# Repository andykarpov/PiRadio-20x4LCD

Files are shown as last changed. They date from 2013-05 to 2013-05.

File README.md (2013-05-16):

PiRadio-20x4LCD
=======

Python based internet radio project for RaspberryPi to play internet radio streams and control it using custom atmega328p-based board with 
connected 20x4 character display, rotary encoder, potentiometer, 2xMSGEQ7 board and PT2322 audio processor board.

All hardware-specific EAGLE projects are located under 'schematic' subfolder. 
All required non-standard libraries are available upon request. Some of them are self-made from scratch, some of them googled in the internet.

**Prerequesties:**

1. You should have a working raspberry pi with latest raspbian (at least 2012-12-18)
2. Also we assumes that your network connection (wired or wireless) is also running well
3. Your arduino-based board is connected via internal on-board serial port  
   (assuming arduino/PyRadioInterface sketch is already uploaded there, all external hardware is connected to the arduino - 
   such as rotary encoder, potentiometer, PT2322 board, MSGEQ7 board)
4. You are logged in as user 'pi' with it's default home at /home/pi/ 

**Installation:**

1. sudo apt-get update && sudo apt-get upgrade
2. sudo apt-get install mpd mpc python-serial python-mpd2 git
3. cd && git clone https://github.com/andykarpov/PiRadio-20x4LCD.git PiRadio
4. cd /home/pi/PiRadio
5. sudo ln -s /home/pi/PiRadio/etc/init.d/pi-radio /etc/init.d/pi-radio
6. chmod -R a+rwx data/ 
7. cd /home/pi/PiRadio/init.d/
8. sudo chmod a+x pi-radio
9. sudo nano /etc/mpd - change "localhost" to "any"
10. sudo alsamixer - set a desired output level
11. sudo alsactl store
12. sudo /etc/init.d/pi-radio start
13. sudo update-rc.d pi-radio defaults
14. sudo reboot

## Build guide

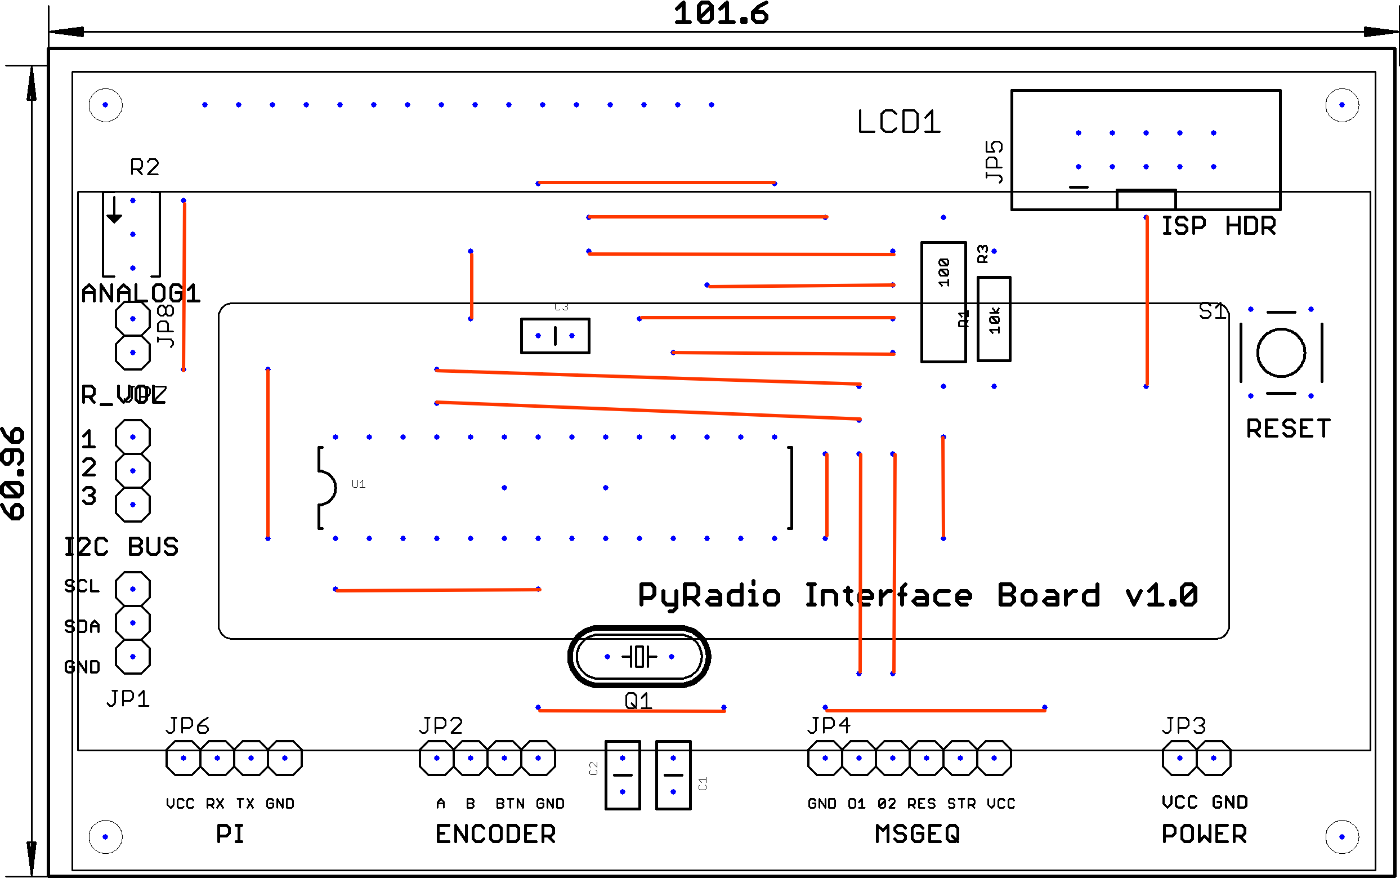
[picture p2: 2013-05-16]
schematic/build/png/interface_v_1_0_pcb_cmp_jumpered.png

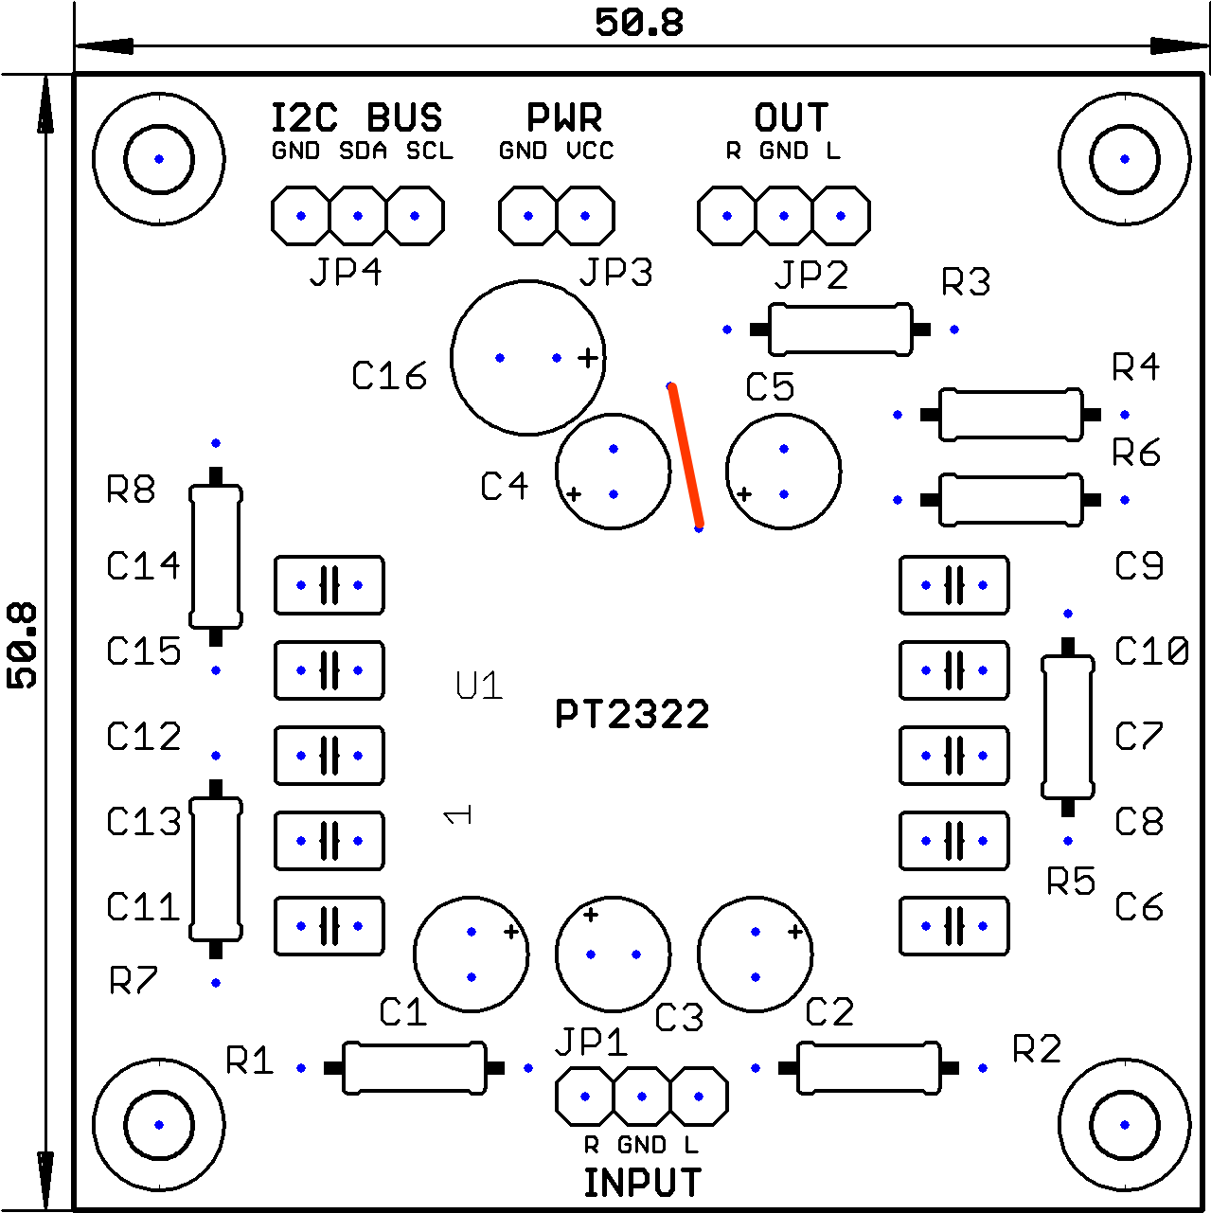
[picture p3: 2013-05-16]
schematic/build/png/pt2322_v_1_0_pcb_cmp_jumpered.png

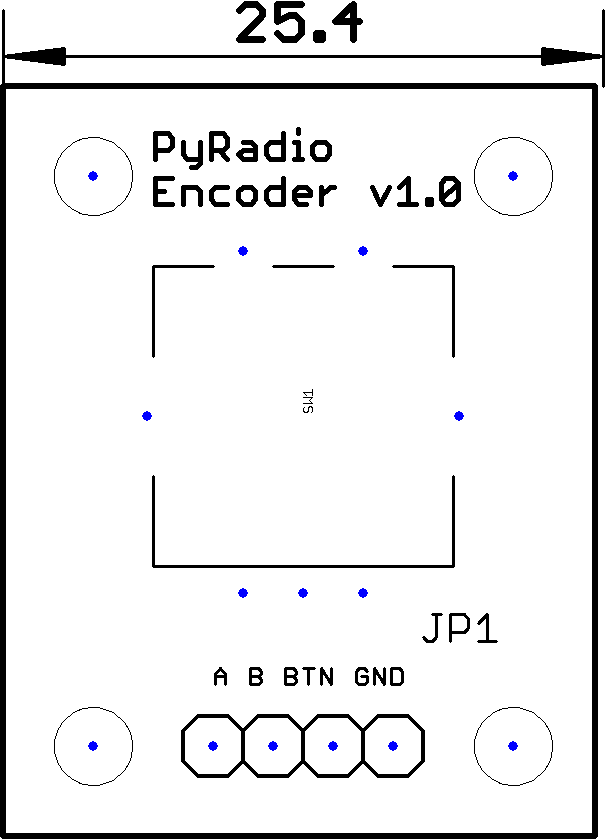
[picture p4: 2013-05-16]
schematic/build/png/encoder_v_1_0_pcb_cmp.png

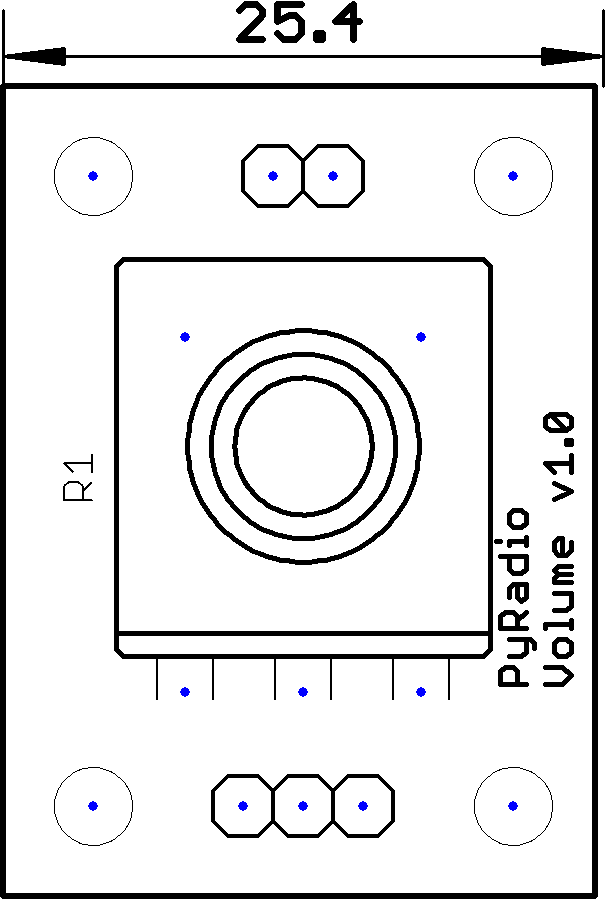
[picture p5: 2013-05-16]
schematic/build/png/volume_v_1_0_pcb_cmp.png

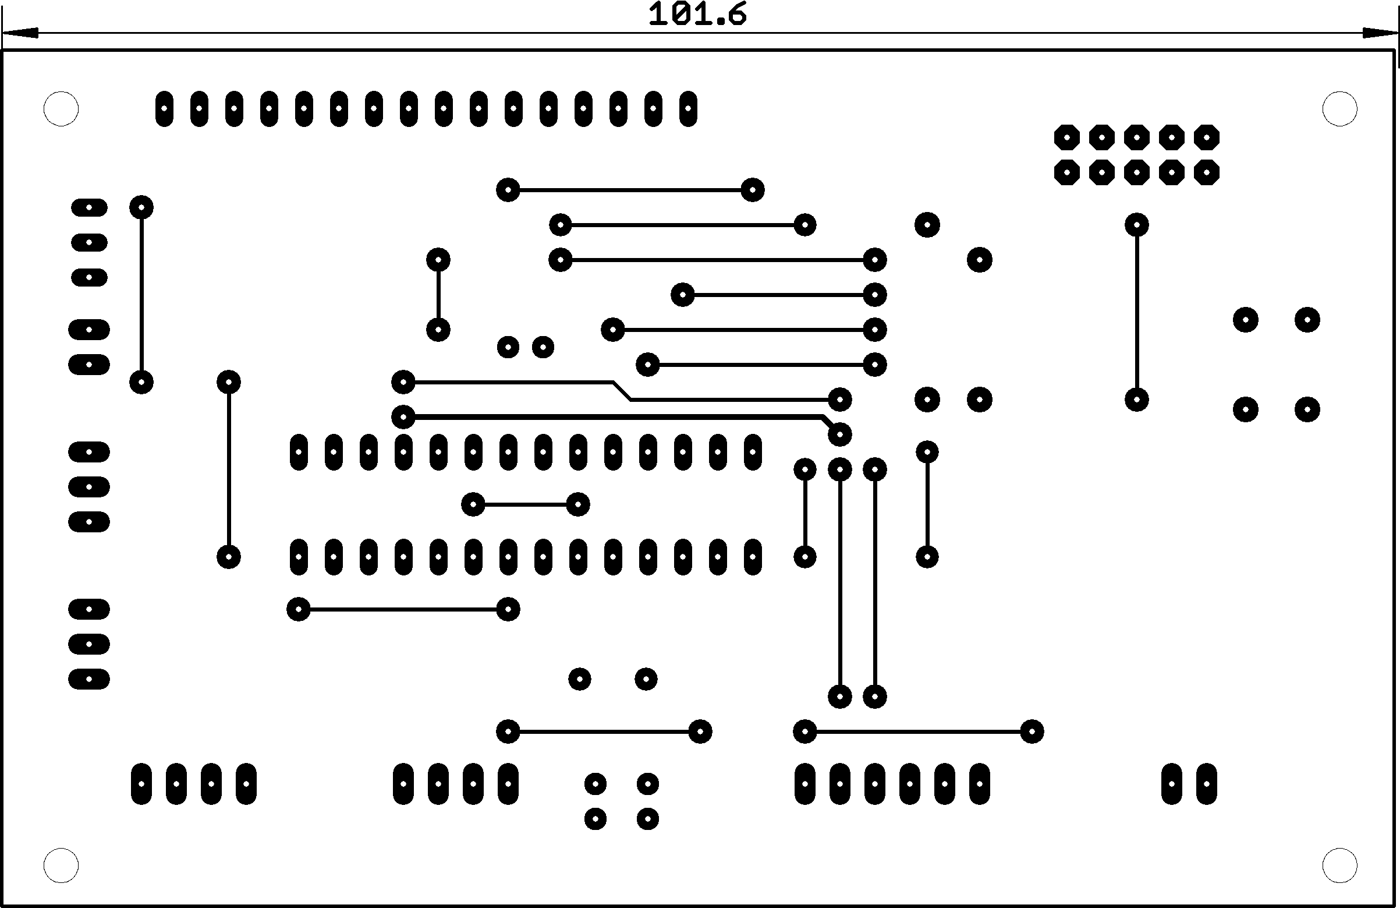
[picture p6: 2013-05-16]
schematic/build/png/interface_v_1_0_pcb_top.png

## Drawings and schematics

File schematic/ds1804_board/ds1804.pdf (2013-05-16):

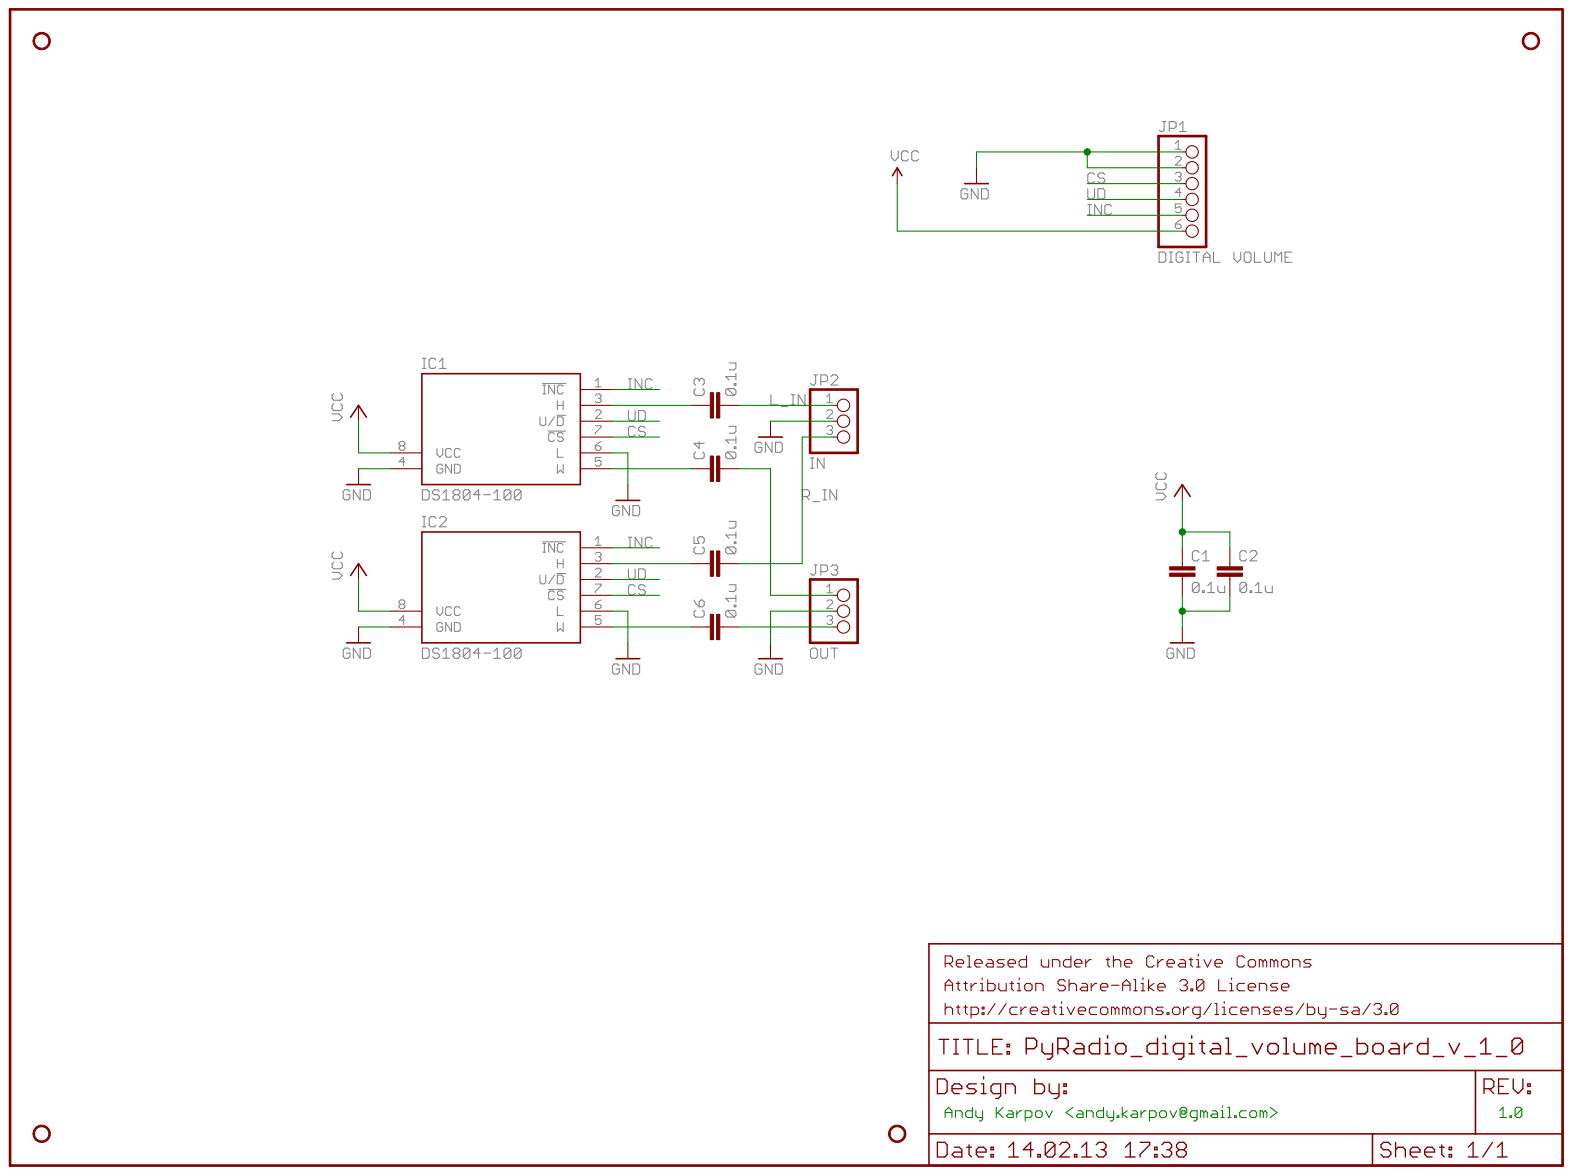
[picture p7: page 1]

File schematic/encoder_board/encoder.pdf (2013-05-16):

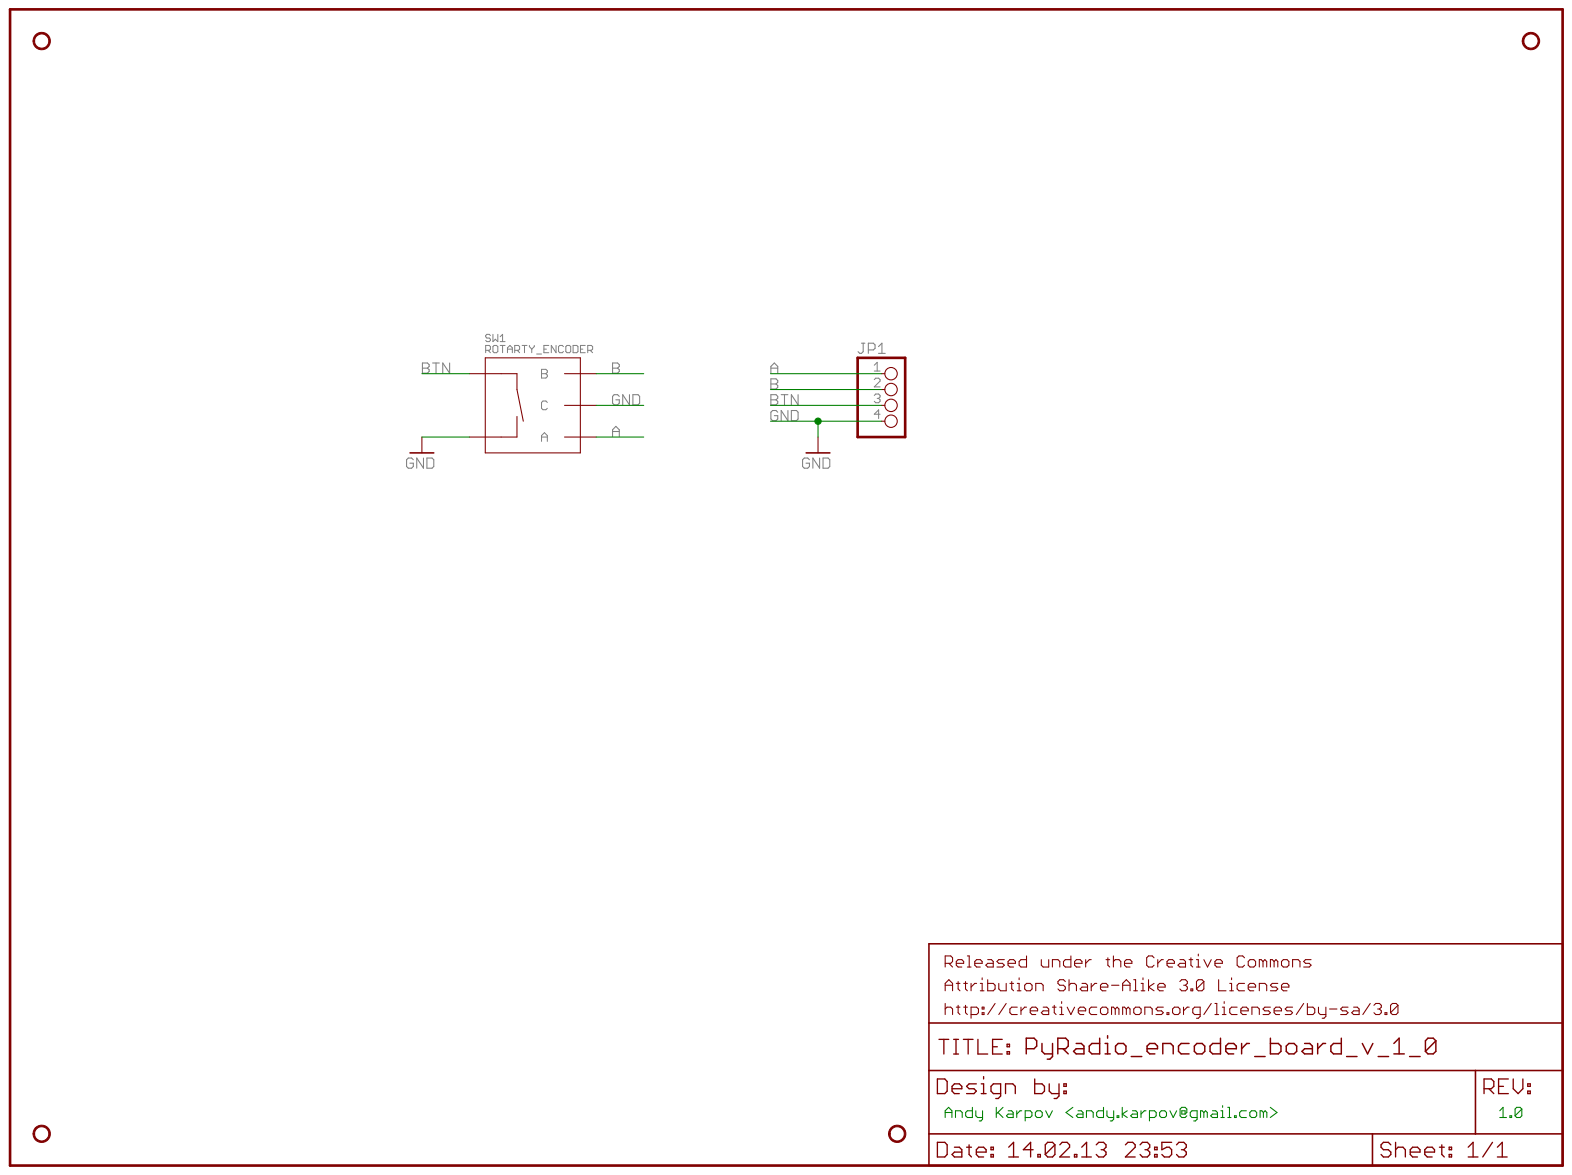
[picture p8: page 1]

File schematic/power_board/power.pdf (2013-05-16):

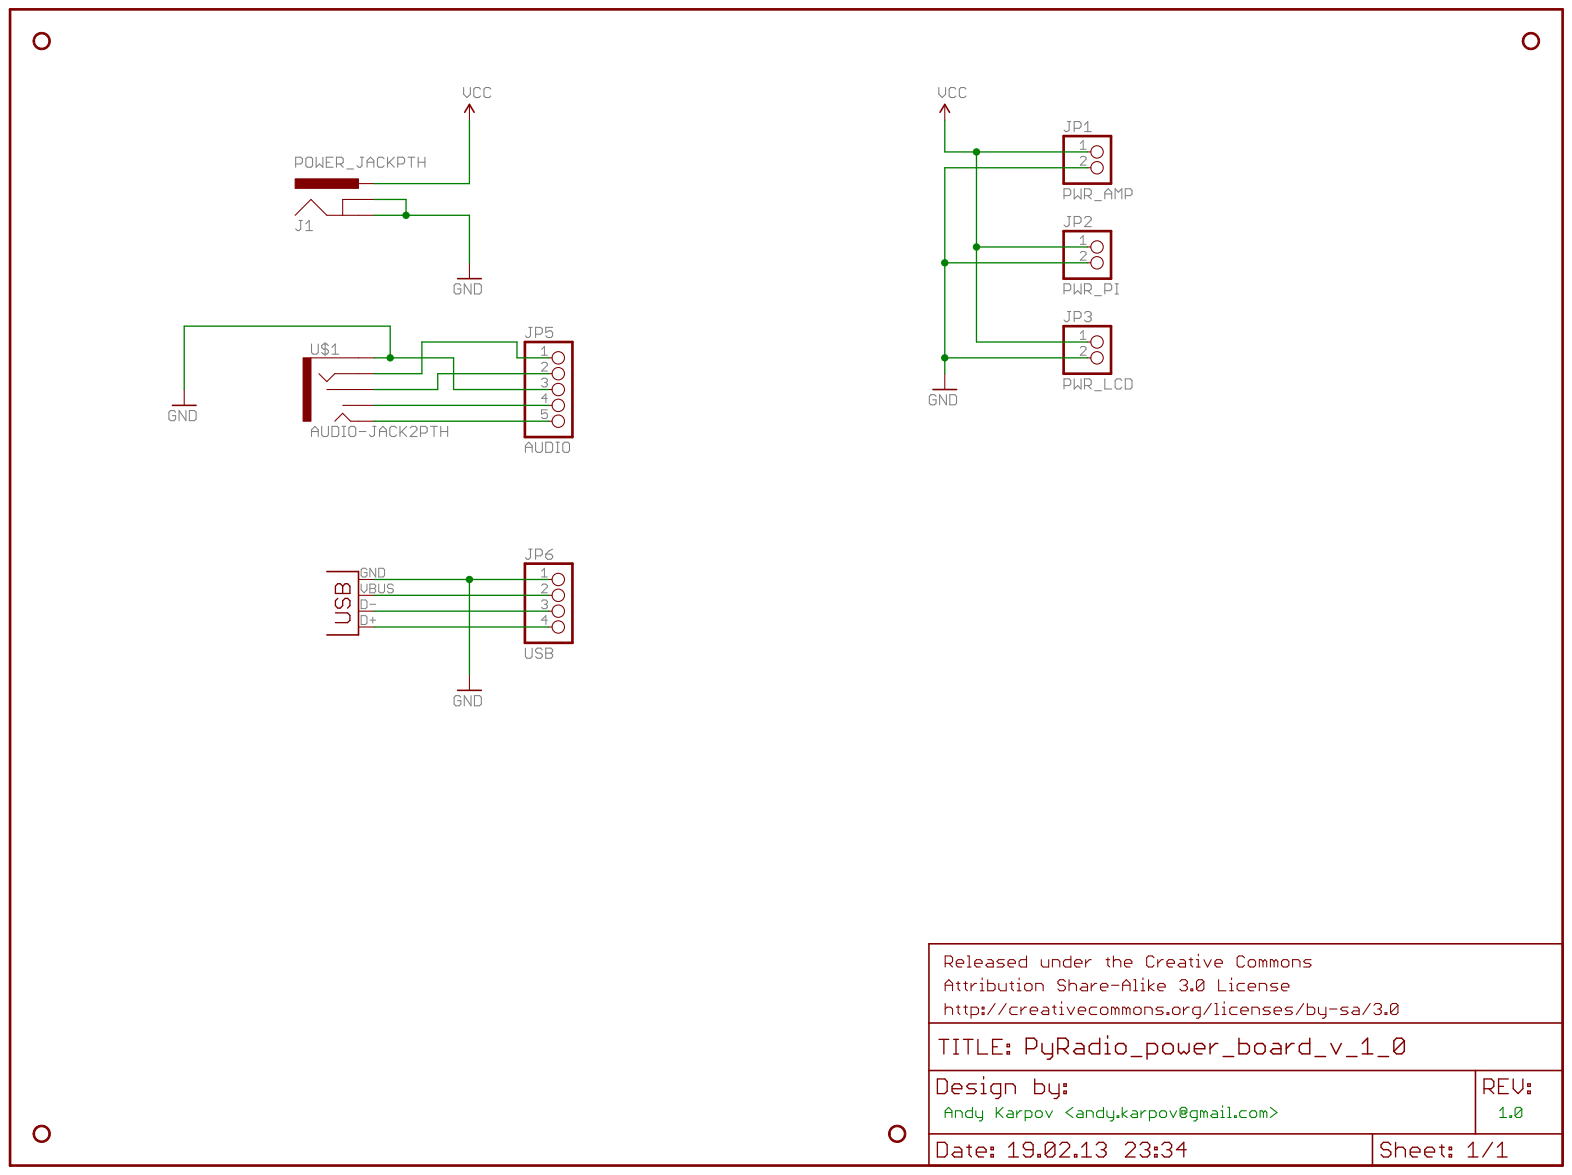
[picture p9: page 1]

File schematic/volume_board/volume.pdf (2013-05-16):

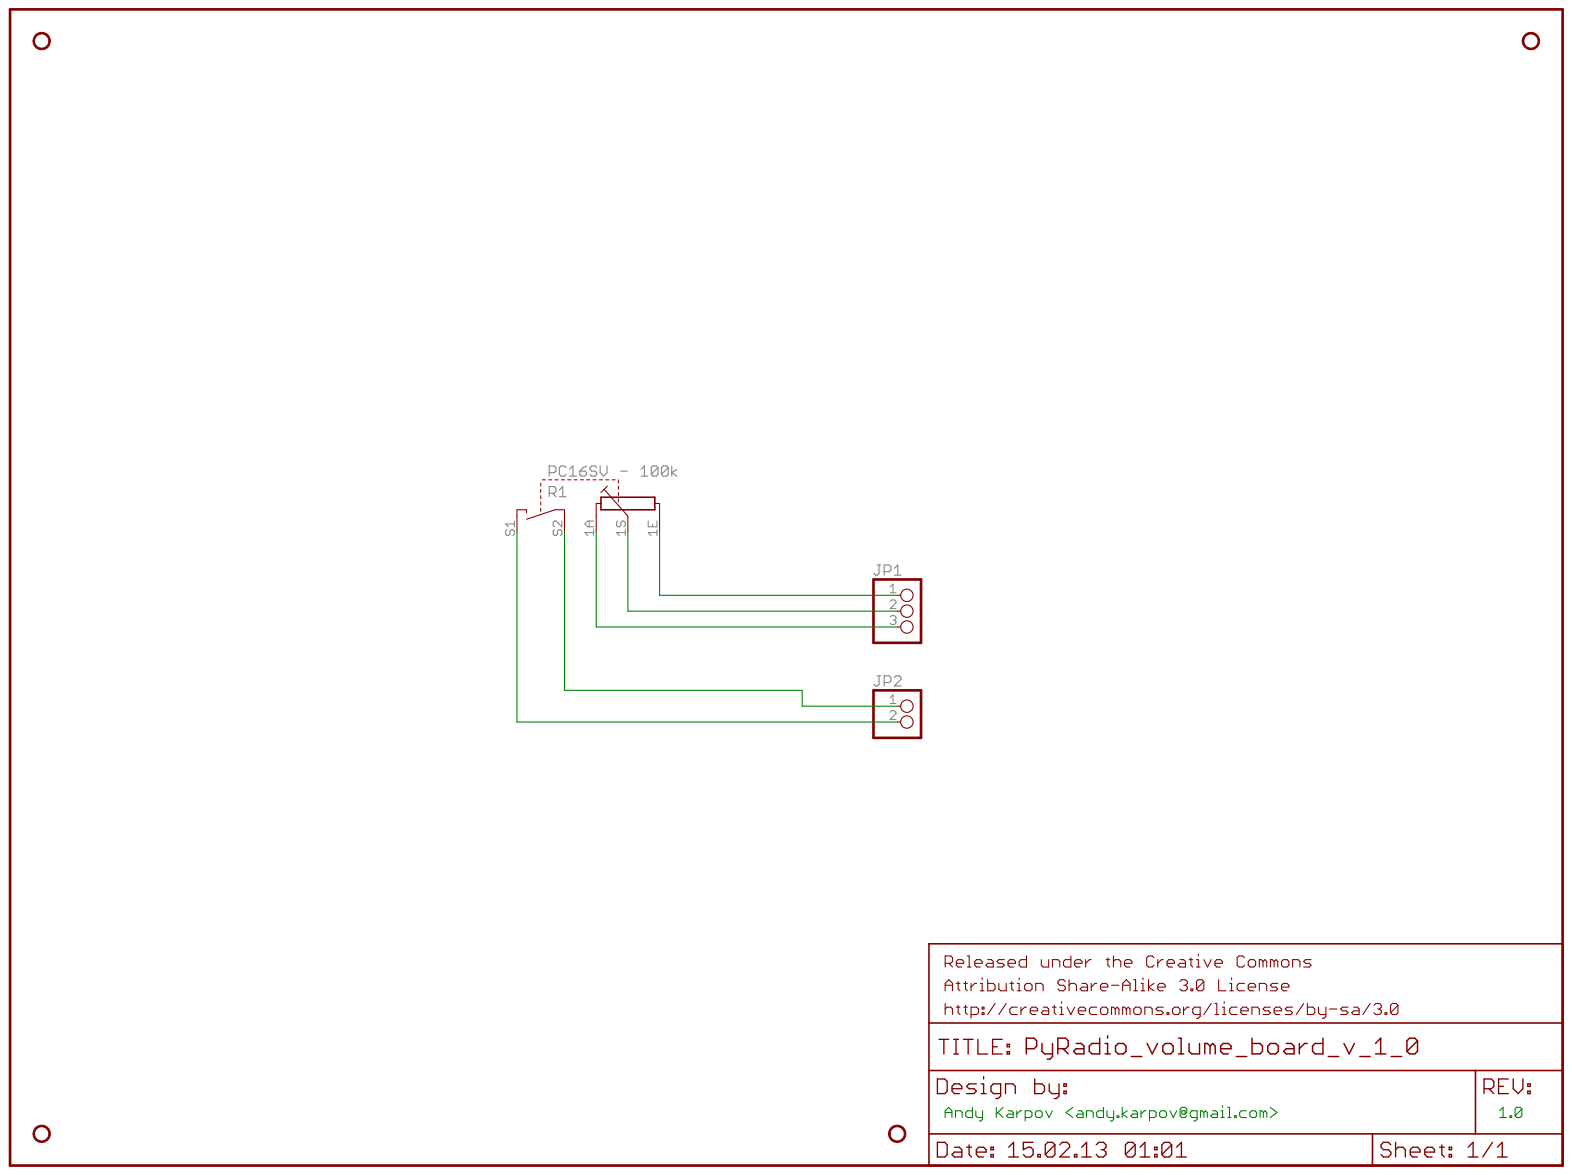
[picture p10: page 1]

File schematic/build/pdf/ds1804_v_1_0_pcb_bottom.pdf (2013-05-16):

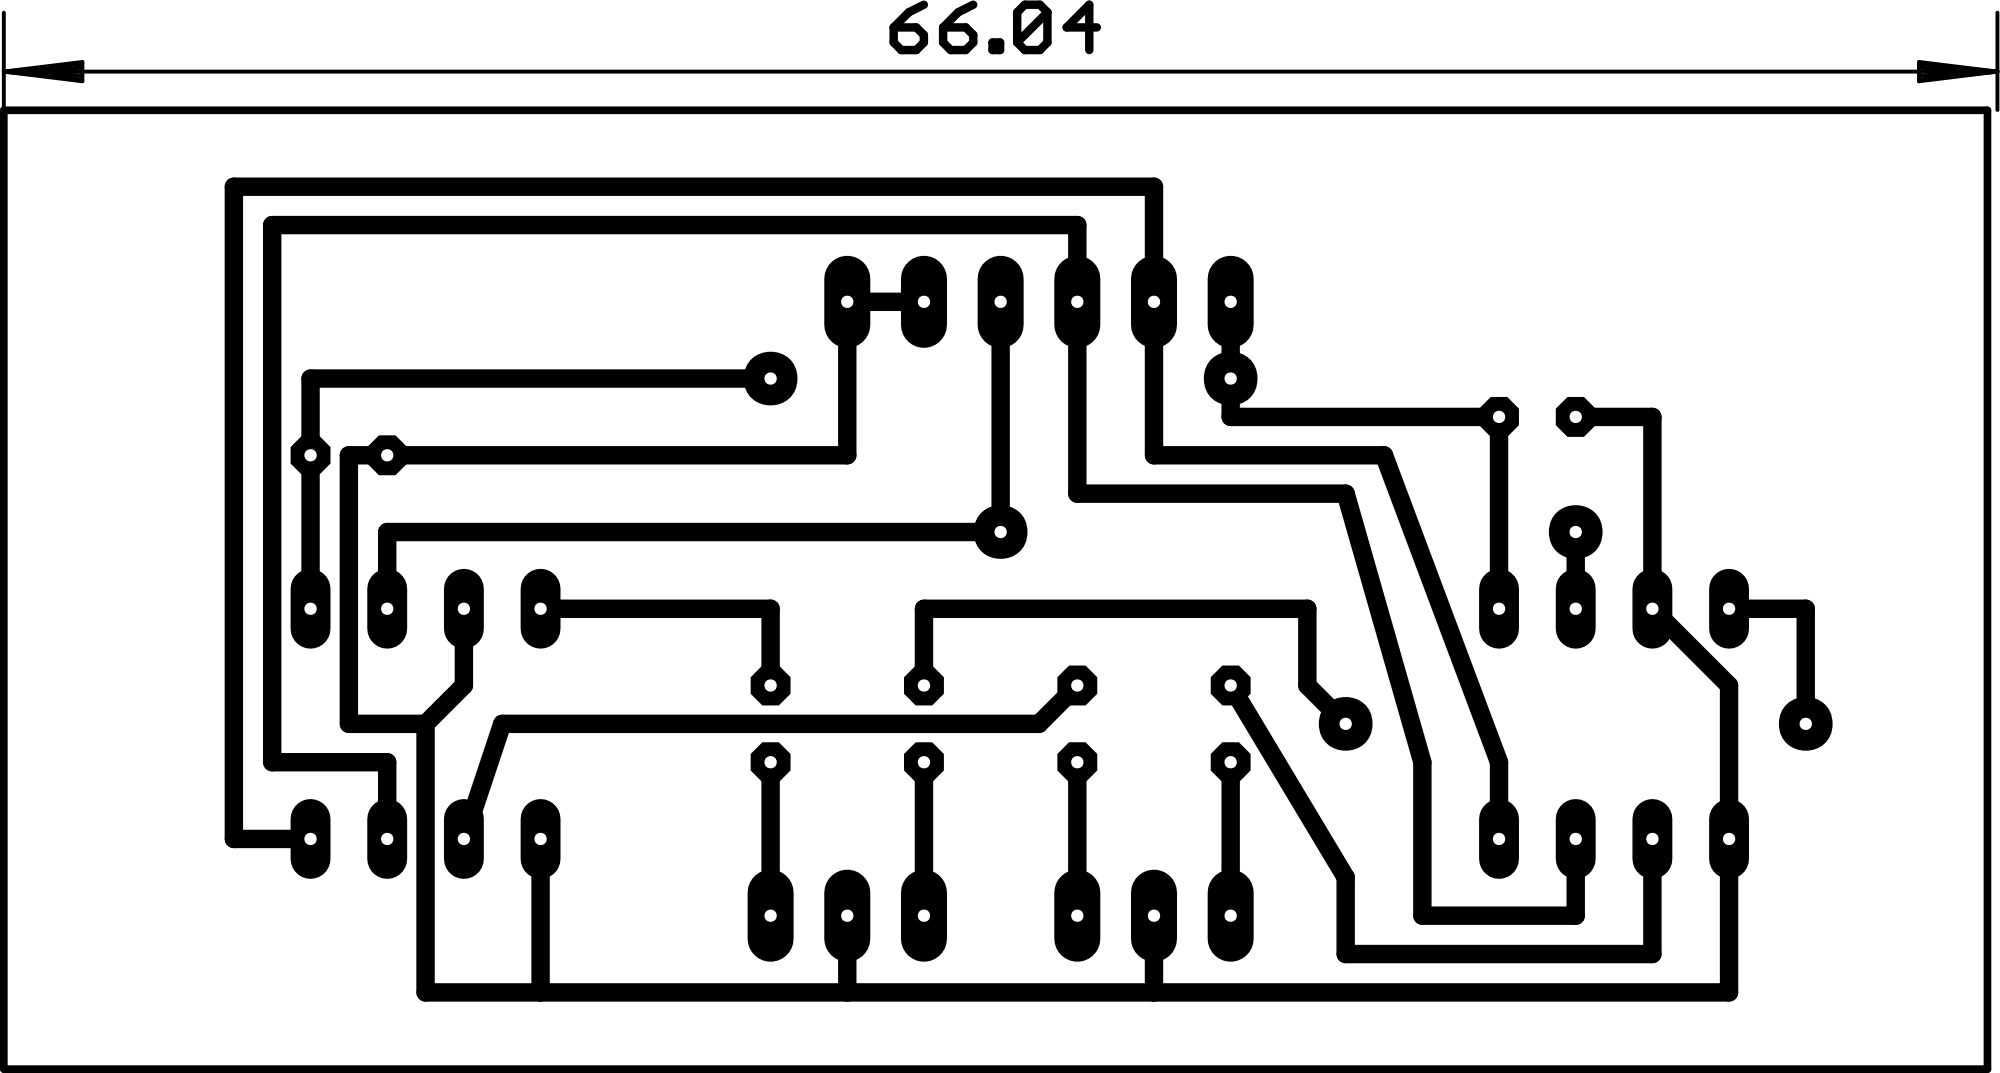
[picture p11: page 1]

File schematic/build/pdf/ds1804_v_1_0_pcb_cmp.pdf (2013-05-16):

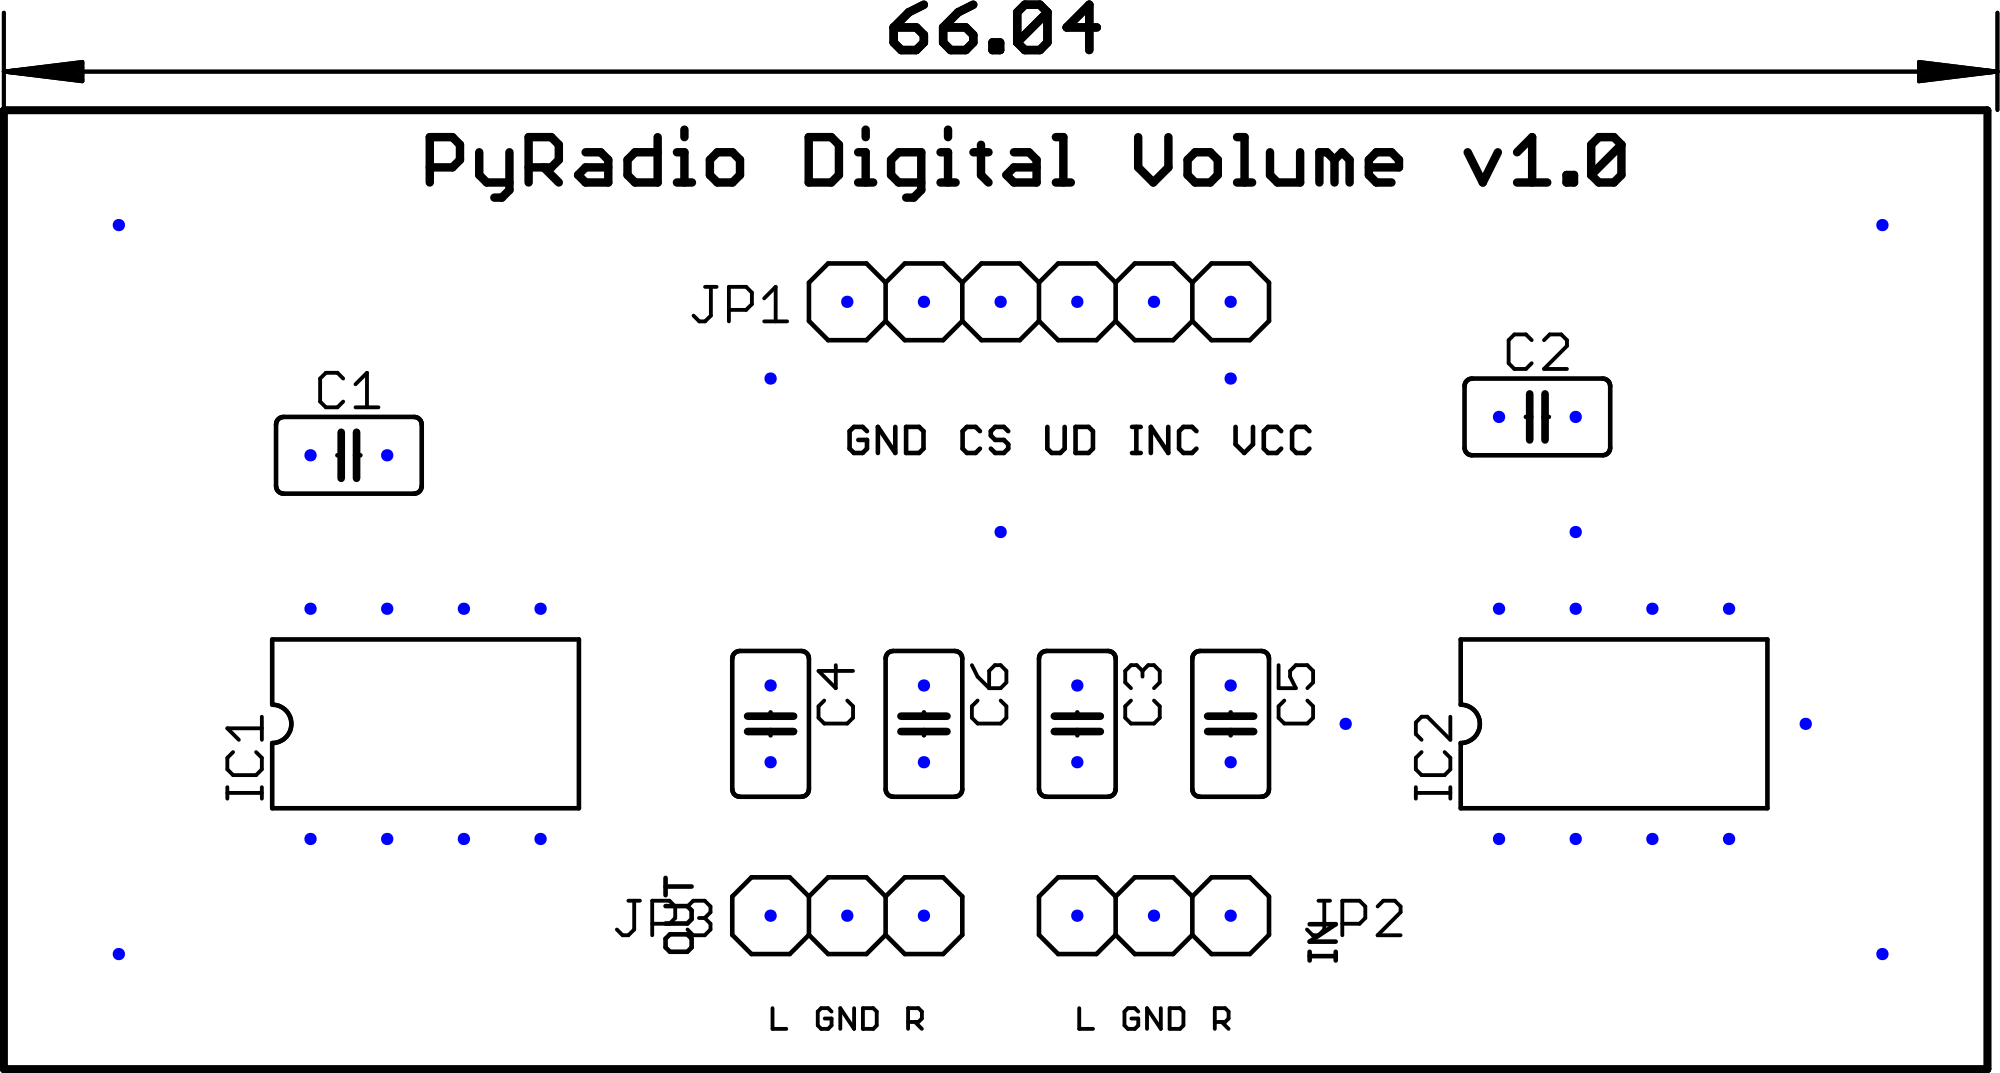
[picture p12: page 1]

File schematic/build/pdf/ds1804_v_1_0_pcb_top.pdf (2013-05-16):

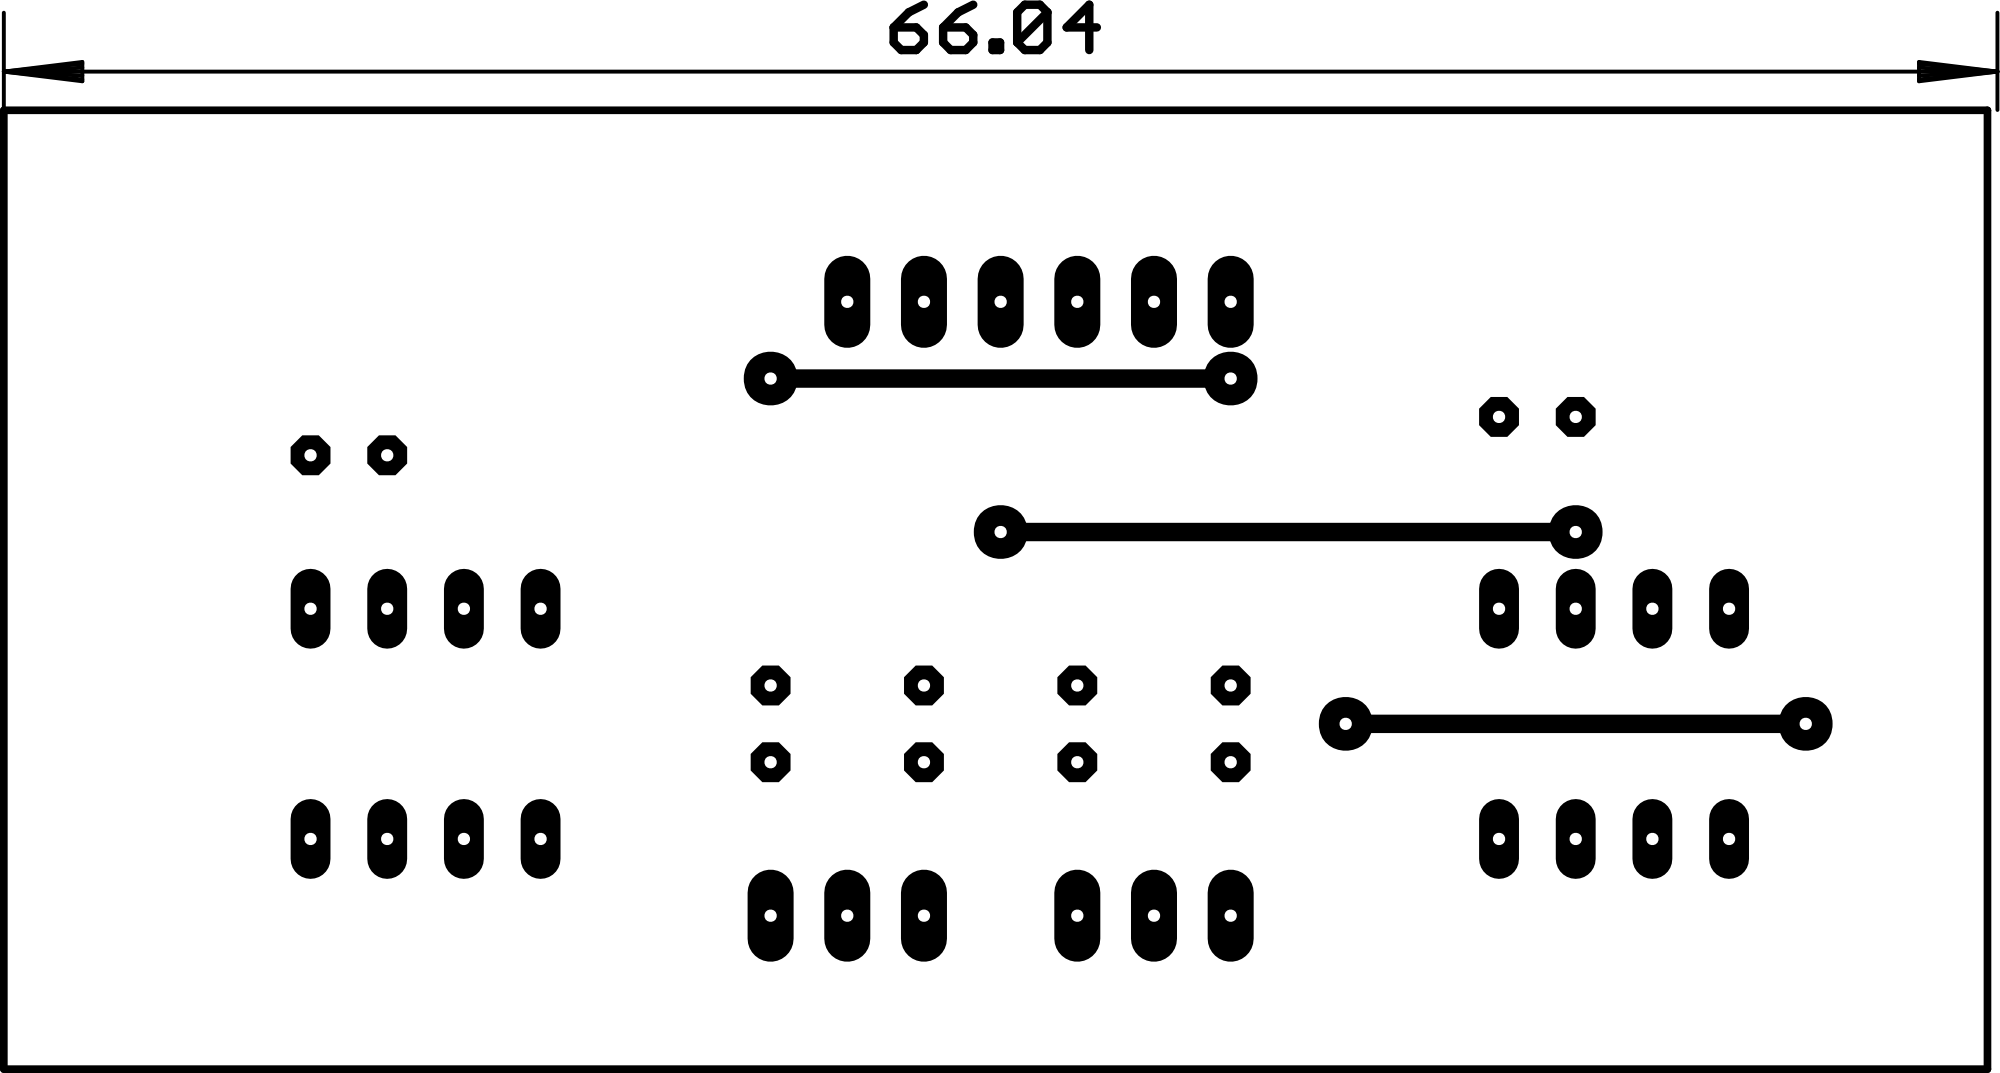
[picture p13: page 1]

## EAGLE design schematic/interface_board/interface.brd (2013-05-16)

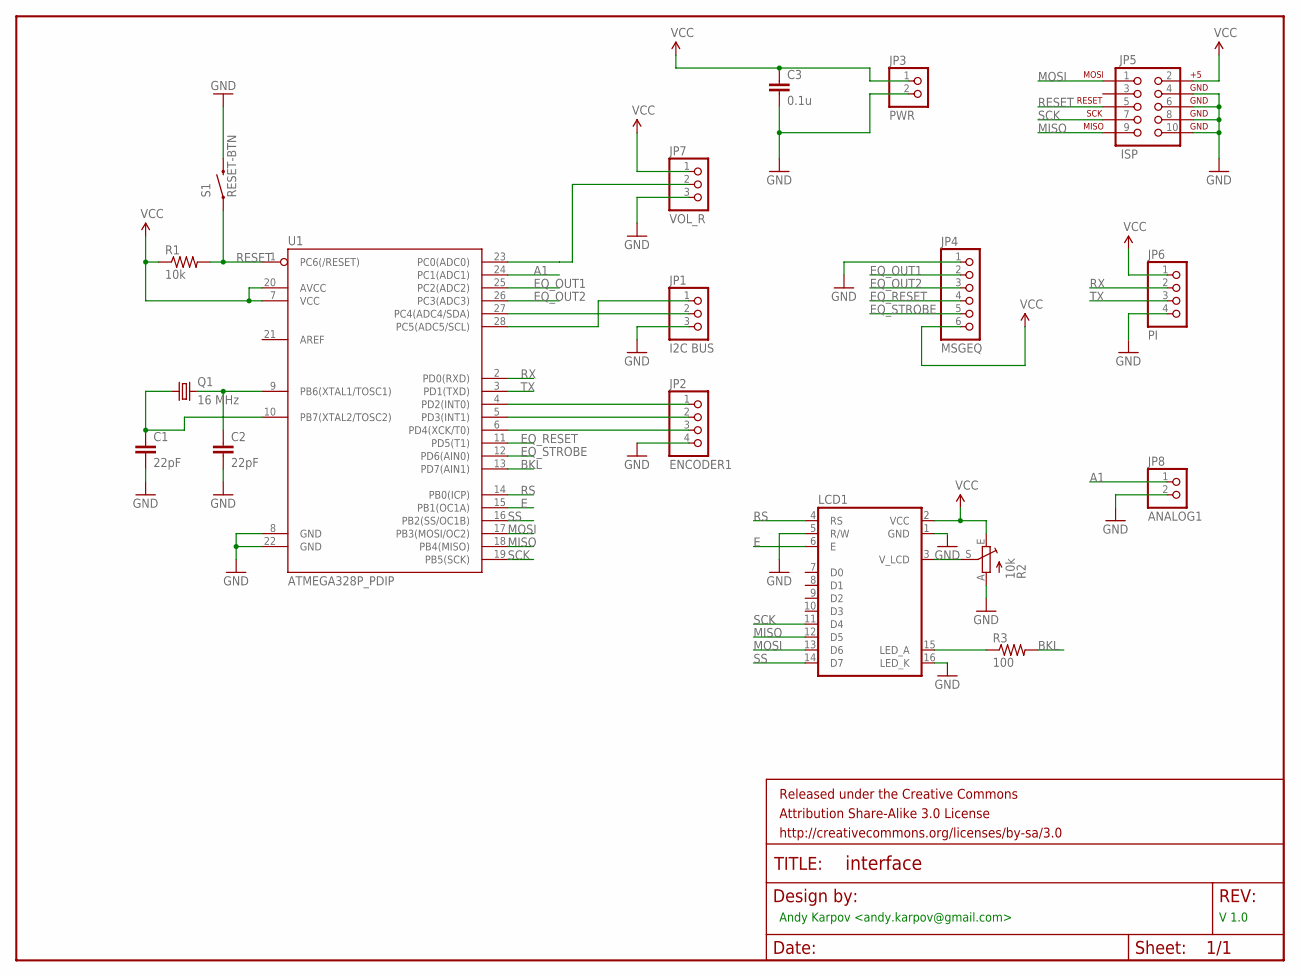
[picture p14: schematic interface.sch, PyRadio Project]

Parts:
C1, C2: 22pF; CAP-PTH-SMALL2
C3: 0.1u; CAP-PTH-SMALL2
FRAME1: FRAME-LETTER; CREATIVE_COMMONS
JP1: I2C BUS; 1X03
JP2: ENCODER1; 1X04
JP3: PWR; 1X02
JP4: MSGEQ; 1X06
JP5: ISP; 2X5-SHROUDED
JP6: PI; 1X04
JP7: VOL_R; 1X03
JP8: ANALOG1; 1X02
LCD1: LCD-4X20
Q1: 16 MHz; HC49/S
R1: 10k; AXIAL-0.4
R2: 10k; B64Y
R3: 100; AXIAL-0.5
S1: RESET-BTN; TACTILE-PTH
U1: ATMEGA328P_PDIP; DIL28-3

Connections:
A1: JP8.1, U1.24 (PC1(ADC1))
BKL: R3.P$2 (2), U1.13 (PD7(AIN1))
E: LCD1.6 (E), U1.15 (PB1(OC1A))
EQ_OUT1: JP4.2, U1.25 (PC2(ADC2))
EQ_OUT2: JP4.3, U1.26 (PC3(ADC3))
EQ_RESET: JP4.4, U1.11 (PD5(T1))
EQ_STROBE: JP4.5, U1.12 (PD6(AIN0))
GND: C1.2, C2.2, C3.2, JP1.3, JP2.4, JP3.2, JP4.1, JP5.4, JP5.6, JP5.8, JP5.10, JP6.4, JP7.3, JP8.2, LCD1.1 (GND), LCD1.5 (R/W), LCD1.16 (LED_K), R2.A, S1.3 (2), U1.8 (GND), U1.22 (GND)
MISO: JP5.9, LCD1.12 (D5), U1.18 (PB4(MISO))
MOSI: JP5.1, LCD1.13 (D6), U1.17 (PB3(MOSI/OC2))
unnamed: C2.1, Q1.2, U1.9 (PB6(XTAL1/TOSC1))
unnamed: C1.1, Q1.1, U1.10 (PB7(XTAL2/TOSC2))
unnamed: LCD1.3 (V_LCD), R2.S
unnamed: JP1.2, U1.27 (PC4(ADC4/SDA))
unnamed: JP1.1, U1.28 (PC5(ADC5/SCL))
unnamed: LCD1.15 (LED_A), R3.P$1 (1)
unnamed: JP2.3, U1.6 (PD4(XCK/T0))
unnamed: JP2.1, U1.4 (PD2(INT0))
unnamed: JP2.2, U1.5 (PD3(INT1))
PC0: JP7.2, U1.23 (PC0(ADC0))
RESET: JP5.5, R1.P$2 (2), S1.1, U1.1 (PC6(/RESET))
RS: LCD1.4 (RS), U1.14 (PB0(ICP))
RX: JP6.2, U1.2 (PD0(RXD))
SCK: JP5.7, LCD1.11 (D4), U1.19 (PB5(SCK))
SS: LCD1.14 (D7), U1.16 (PB2(SS/OC1B))
TX: JP6.3, U1.3 (PD1(TXD))
VCC: C3.1, JP3.1, JP4.6, JP5.2, JP6.1, JP7.1, LCD1.2 (VCC), R1.P$1 (1), R2.E, U1.7 (VCC), U1.20 (AVCC)

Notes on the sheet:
Andy Karpov <andy.karpov@gmail.com>
V 1.0

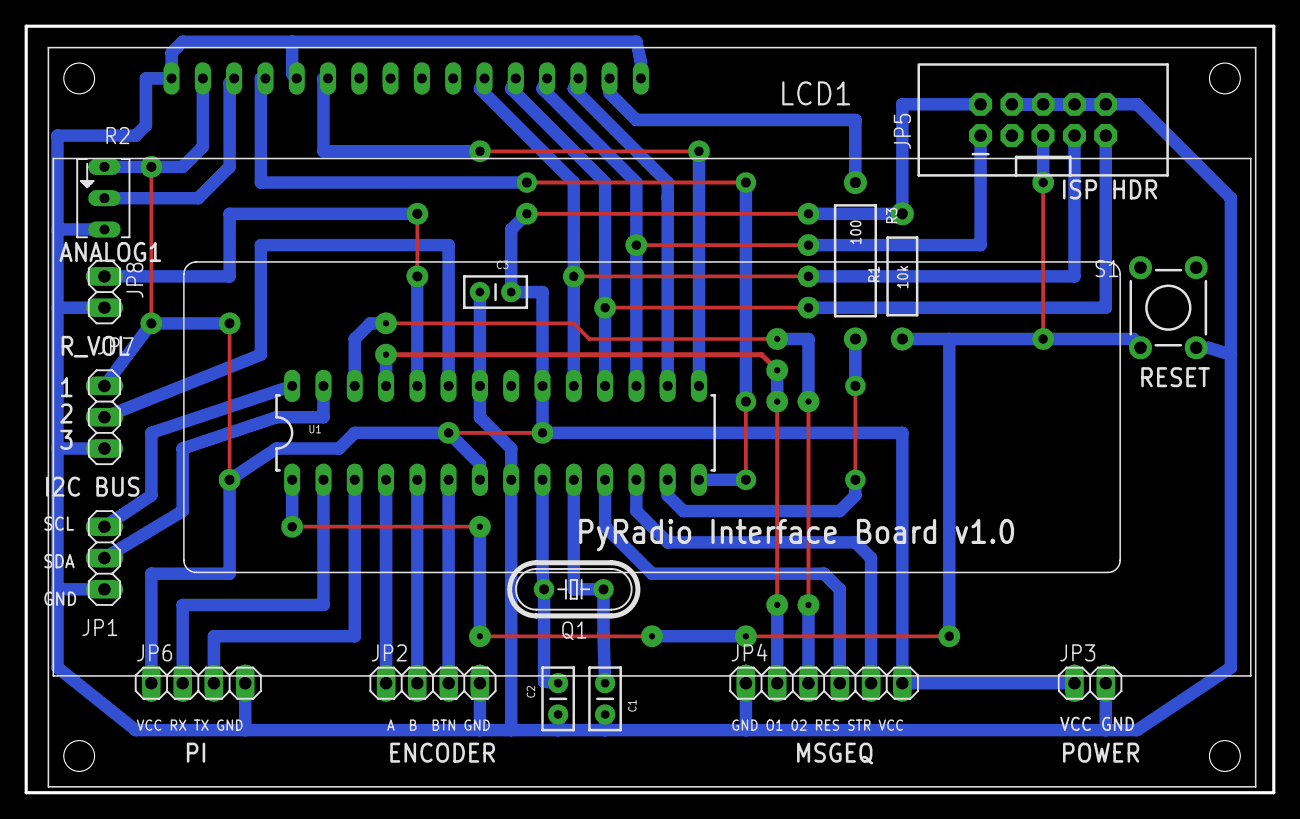
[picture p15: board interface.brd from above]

Board: 2 copper layers, 101.3 x 62.2 mm, 19 parts (0 on the bottom side), 27 nets.

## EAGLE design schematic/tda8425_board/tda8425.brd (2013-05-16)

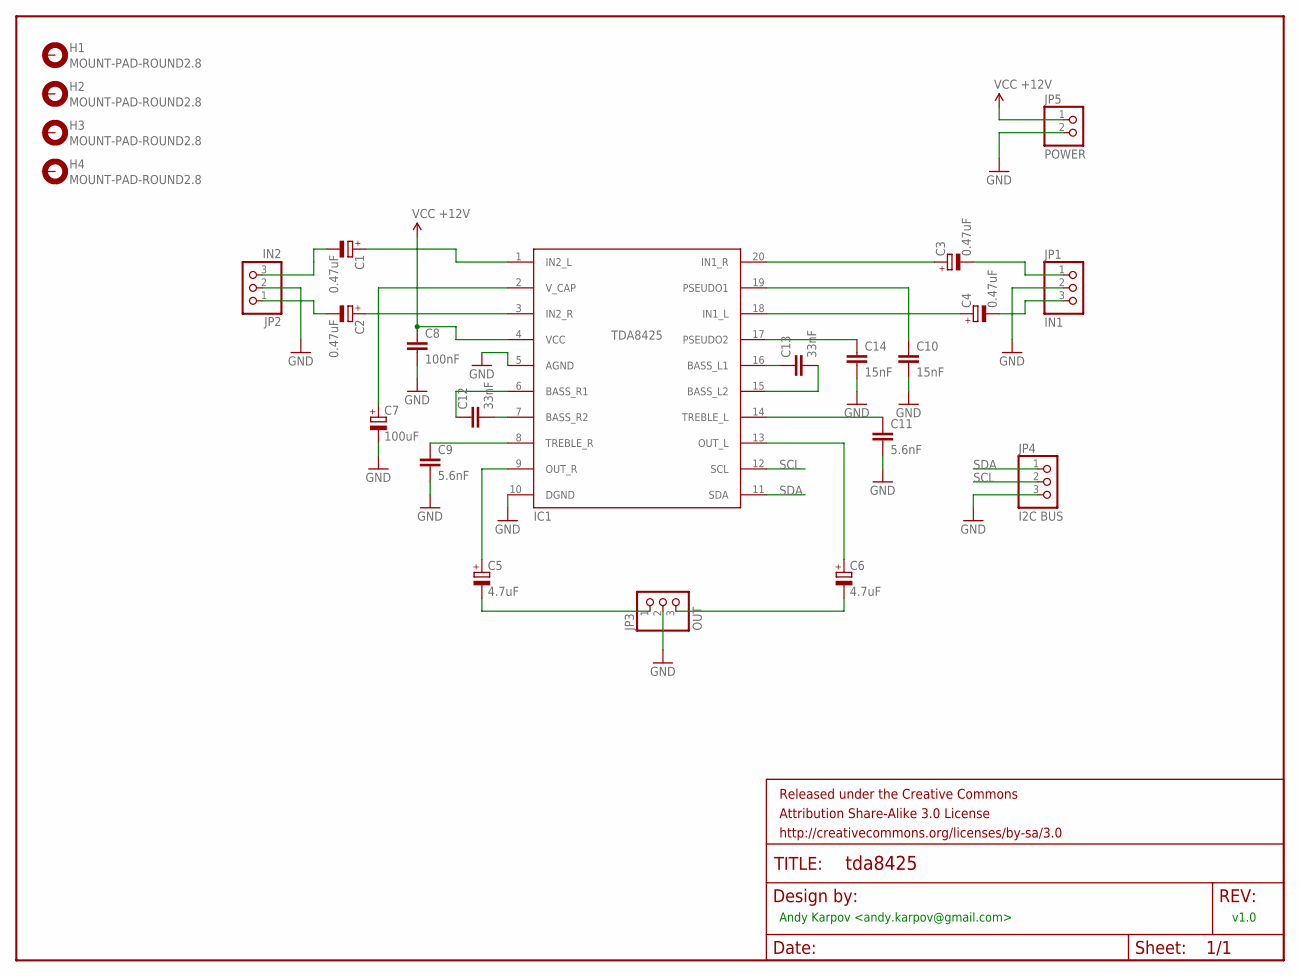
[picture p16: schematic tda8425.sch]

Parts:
C1, C2, C3, C4: 0.47uF; E2,5-6
C5, C6: 4.7uF; E2,5-6
C7: 100uF; E2,5-6
C8: 100nF; C025-025X050
C9, C11: 5.6nF; C025-025X050
C10, C14: 15nF; C025-025X050
C12, C13: 33nF; C025-025X050
FRAME1: FRAME-LETTER; CREATIVE_COMMONS
H1, H2, H3, H4: MOUNT-PAD-ROUND2.8; 2,8-PAD
IC1: TDA8425; DIL20
JP1: IN1; 1X03
JP2: IN2; 1X03
JP3: OUT; 1X03
JP4: I2C BUS; 1X03
JP5: POWER; 1X02

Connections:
GND: C7.-, C8.2, C9.2, C10.2, C11.2, C14.2, IC1.5 (AGND), IC1.10 (DGND), JP1.2, JP2.2, JP3.2, JP4.3, JP5.2
unnamed: C1.+, IC1.1 (IN2_L)
unnamed: C1.-, JP2.3
unnamed: C2.+, IC1.3 (IN2_R)
unnamed: C2.-, JP2.1
unnamed: C3.+, IC1.20 (IN1_R)
unnamed: C4.+, IC1.18 (IN1_L)
unnamed: C3.-, JP1.1
unnamed: C4.-, JP1.3
unnamed: C7.+, IC1.2 (V_CAP)
unnamed: C12.1, IC1.6 (BASS_R1)
unnamed: C12.2, IC1.7 (BASS_R2)
unnamed: C9.1, IC1.8 (TREBLE_R)
unnamed: C5.+, IC1.9 (OUT_R)
unnamed: C5.-, JP3.1
unnamed: C6.+, IC1.13 (OUT_L)
unnamed: C6.-, JP3.3
unnamed: C13.1, IC1.16 (BASS_L1)
unnamed: C13.2, IC1.15 (BASS_L2)
unnamed: C14.1, IC1.17 (PSEUDO2)
unnamed: C11.1, IC1.14 (TREBLE_L)
unnamed: C10.1, IC1.19 (PSEUDO1)
SCL: IC1.12 (SCL), JP4.2
SDA: IC1.11 (SDA), JP4.1
VCC: C8.1, IC1.4 (VCC), JP5.1

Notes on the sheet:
Andy Karpov <andy.karpov@gmail.com>
v1.0

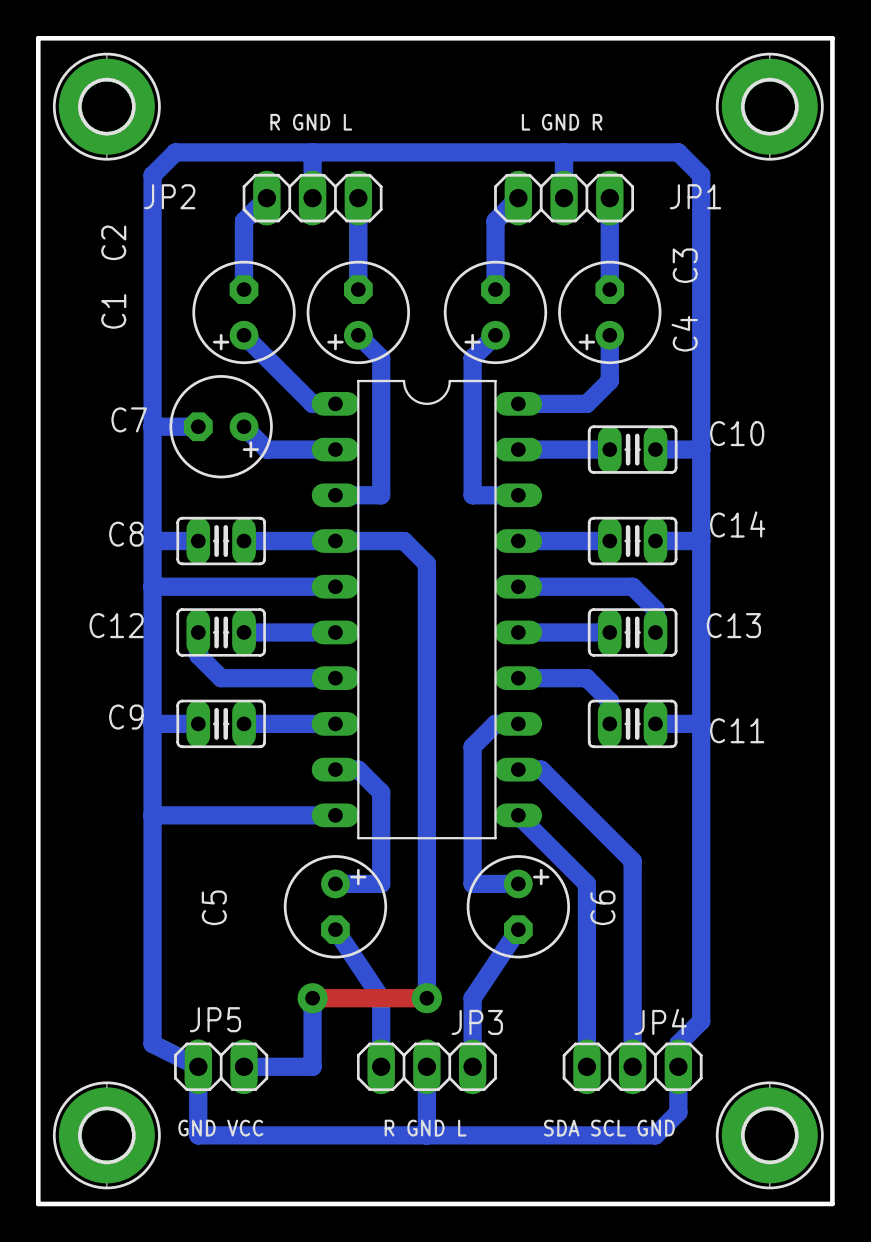
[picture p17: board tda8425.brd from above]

Board: 2 copper layers, 44.1 x 64.8 mm, 25 parts (0 on the bottom side), 25 nets.

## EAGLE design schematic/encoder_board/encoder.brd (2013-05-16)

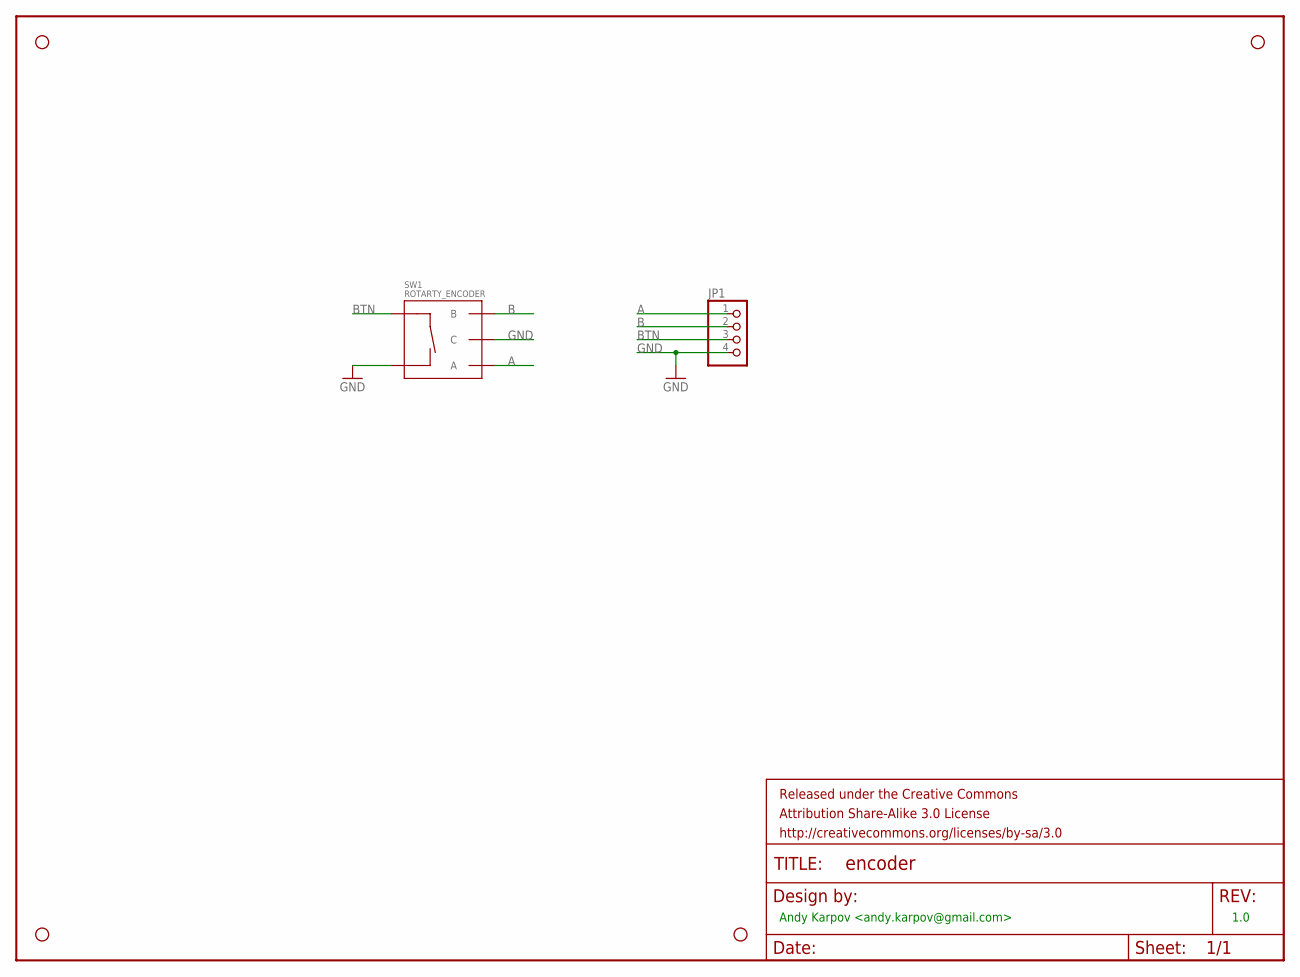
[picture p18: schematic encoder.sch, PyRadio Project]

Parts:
FRAME1: FRAME-LETTER; CREATIVE_COMMONS
JP1: PINHD-1X4; 1X04
STANDOFF1, STANDOFF2, STANDOFF3, STANDOFF4: STAND-OFF
SW1: ROTARTY_ENCODER; ROTARY_ENC_PLAIN

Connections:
A: JP1.1, SW1.A
B: JP1.2, SW1.B
BTN: JP1.3, SW1.SW+
GND: JP1.4, SW1.C, SW1.SW-

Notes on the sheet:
Andy Karpov <andy.karpov@gmail.com>
1.0

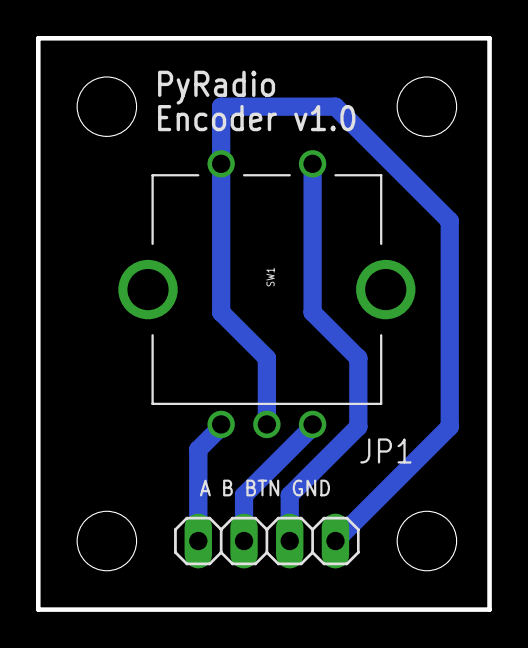
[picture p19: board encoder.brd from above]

Board: 2 copper layers, 25.1 x 31.7 mm, 7 parts (0 on the bottom side), 4 nets.

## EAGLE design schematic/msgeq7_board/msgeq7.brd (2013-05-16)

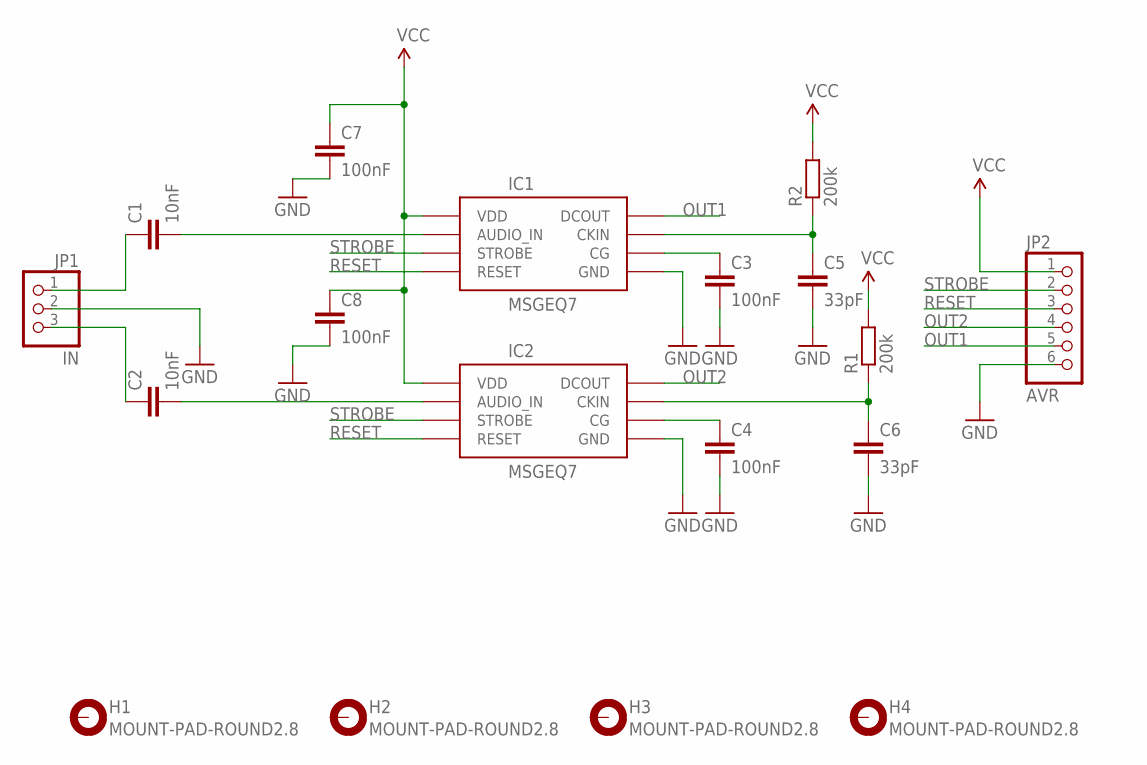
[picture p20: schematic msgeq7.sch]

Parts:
C1, C2: 10nF; C025-030X050
C3, C4: 100nF; C025-030X050
C5, C6: 33pF; C025-030X050
C7, C8: 100nF; C025-025X050
H1, H2, H3, H4: MOUNT-PAD-ROUND2.8; 2,8-PAD
IC1, IC2: MSGEQ7DIP; DIL08
JP1: IN; 1X03
JP2: AVR; 1X06
R1, R2: 200k; 0204/7

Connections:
GND: C3.2, C4.2, C5.2, C6.2, C7.2, C8.2, IC1.2 (GND), IC2.2 (GND), JP1.2, JP2.6
unnamed: C1.1, JP1.1
unnamed: C1.2, IC1.5 (AUDIO_IN)
unnamed: C2.1, JP1.3
unnamed: C2.2, IC2.5 (AUDIO_IN)
unnamed: C3.1, IC1.6 (CG)
unnamed: C4.1, IC2.6 (CG)
unnamed: C5.1, IC1.8 (CKIN), R2.1
unnamed: C6.1, IC2.8 (CKIN), R1.1
OUT1: IC1.3 (DCOUT), JP2.5
OUT2: IC2.3 (DCOUT), JP2.4
RESET: IC1.7 (RESET), IC2.7 (RESET), JP2.3
STROBE: IC1.4 (STROBE), IC2.4 (STROBE), JP2.2
VCC: C7.1, C8.1, IC1.1 (VDD), IC2.1 (VDD), JP2.1, R1.2, R2.2

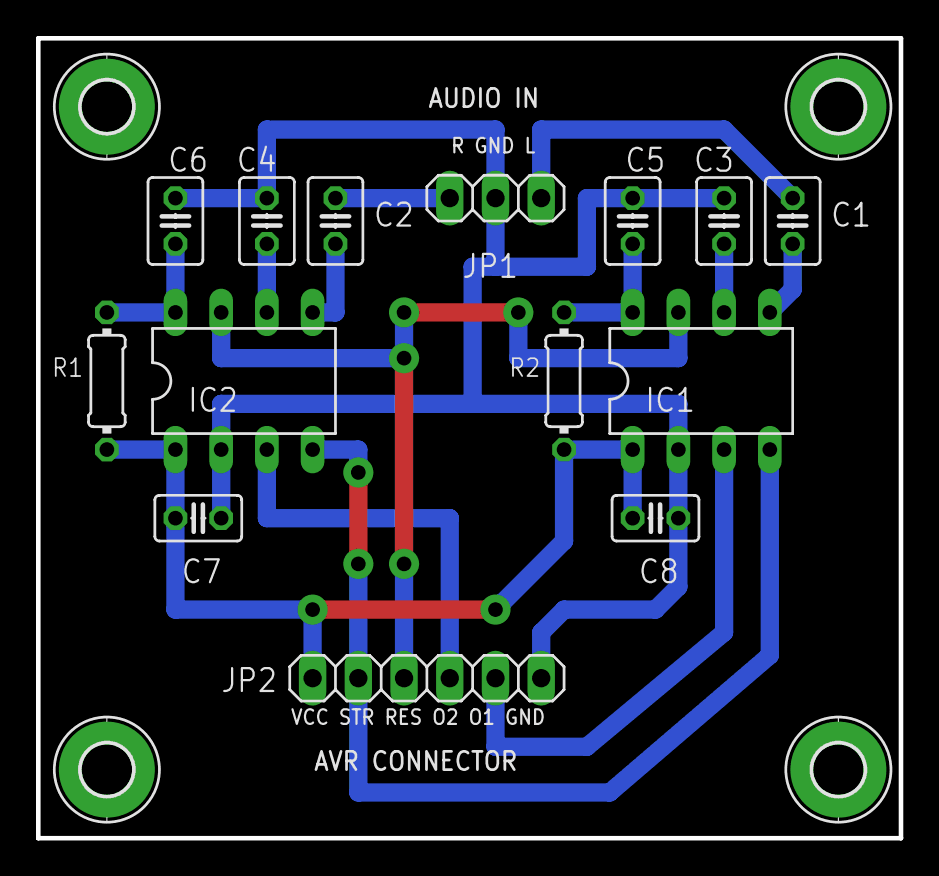
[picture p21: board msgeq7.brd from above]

Board: 2 copper layers, 47.9 x 44.4 mm, 18 parts (0 on the bottom side), 14 nets.

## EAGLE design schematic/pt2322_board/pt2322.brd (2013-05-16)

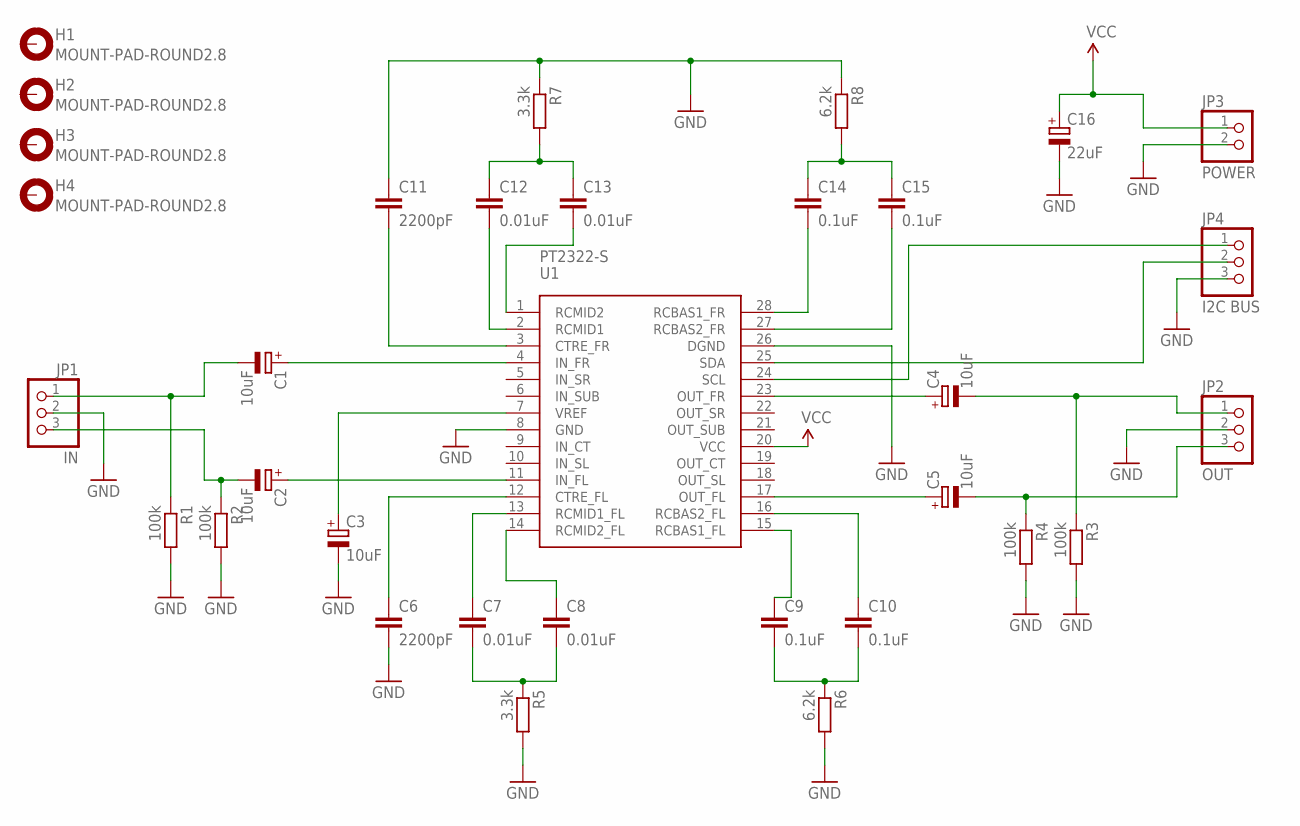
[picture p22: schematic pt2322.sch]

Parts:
C1, C2, C3, C4, C5: 10uF; E2-5
C6, C11: 2200pF; C025-025X050
C7, C8, C12, C13: 0.01uF; C025-025X050
C9, C10, C14, C15: 0.1uF; C025-025X050
C16: 22uF; E2,5-7
H1, H2, H3, H4: MOUNT-PAD-ROUND2.8; 2,8-PAD
JP1: IN; 1X03
JP2: OUT; 1X03
JP3: POWER; 1X02
JP4: I2C BUS; 1X03
R1, R2, R3, R4: 100k; 0207/10
R5, R7: 3.3k; 0207/10
R6, R8: 6.2k; 0207/10
U1: PT2322-S; SOP28

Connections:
GND: C3.-, C6.2, C11.1, C16.-, JP1.2, JP2.2, JP3.2, JP4.3, R1.2, R2.2, R3.2, R4.2, R5.2, R6.2, R7.1, R8.1, U1.8 (GND), U1.26 (DGND)
unnamed: C1.+, U1.4 (IN_FR)
unnamed: C2.+, U1.11 (IN_FL)
unnamed: C1.-, JP1.1, R1.1
unnamed: C2.-, JP1.3, R2.1
unnamed: C3.+, U1.7 (VREF)
unnamed: C6.1, U1.12 (CTRE_FL)
unnamed: C7.1, U1.13 (RCMID1_FL)
unnamed: C8.1, U1.14 (RCMID2_FL)
unnamed: C7.2, C8.2, R5.1
unnamed: C10.1, U1.16 (RCBAS2_FL)
unnamed: C9.1, U1.15 (RCBAS1_FL)
unnamed: C9.2, C10.2, R6.1
unnamed: C13.2, U1.1 (RCMID2)
unnamed: C12.2, U1.2 (RCMID1)
unnamed: C11.2, U1.3 (CTRE_FR)
unnamed: C12.1, C13.1, R7.2
unnamed: C14.2, U1.28 (RCBAS1_FR)
unnamed: C15.2, U1.27 (RCBAS2_FR)
unnamed: C14.1, C15.1, R8.2
unnamed: C4.+, U1.23 (OUT_FR)
unnamed: C5.+, U1.17 (OUT_FL)
unnamed: C4.-, JP2.1, R3.1
unnamed: C5.-, JP2.3, R4.1
unnamed: JP4.1, U1.24 (SCL)
unnamed: JP4.2, U1.25 (SDA)
VCC: C16.+, JP3.1, U1.20 (VCC)

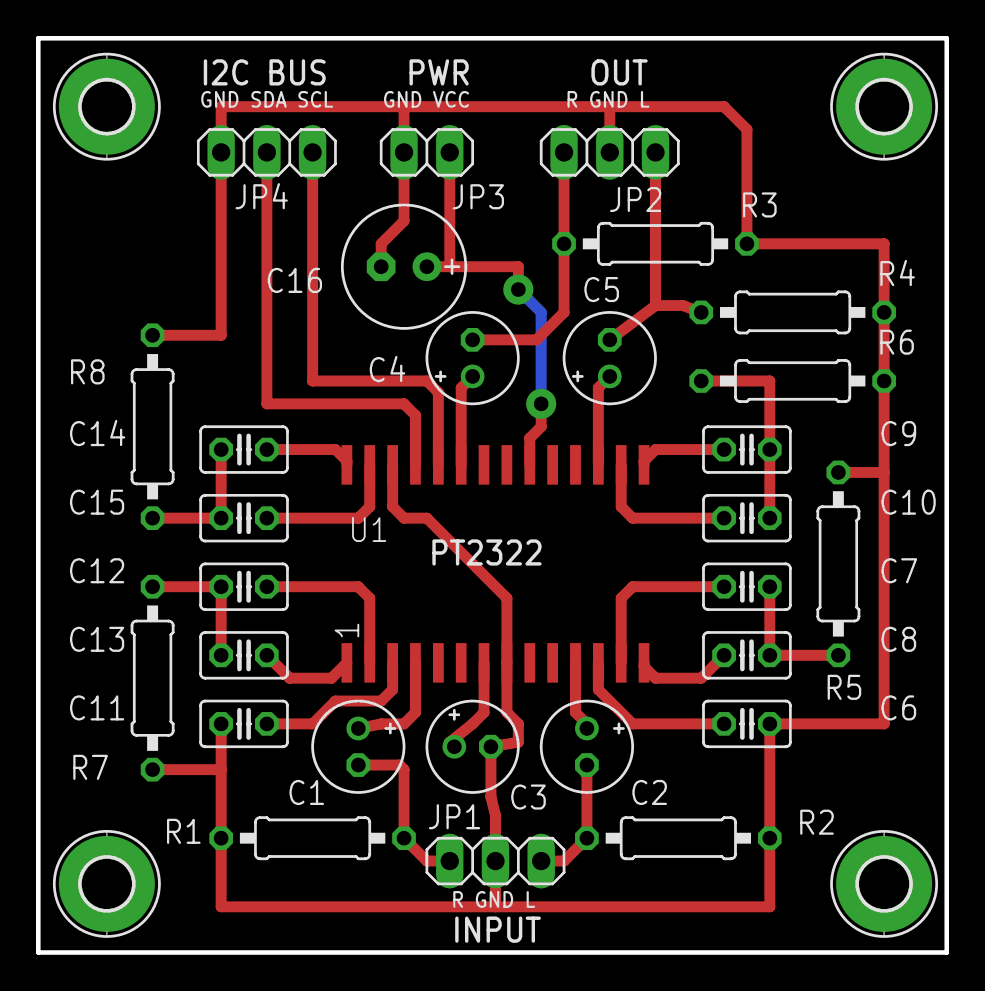
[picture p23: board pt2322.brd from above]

Board: 2 copper layers, 50.5 x 50.8 mm, 33 parts (0 on the bottom side), 27 nets.

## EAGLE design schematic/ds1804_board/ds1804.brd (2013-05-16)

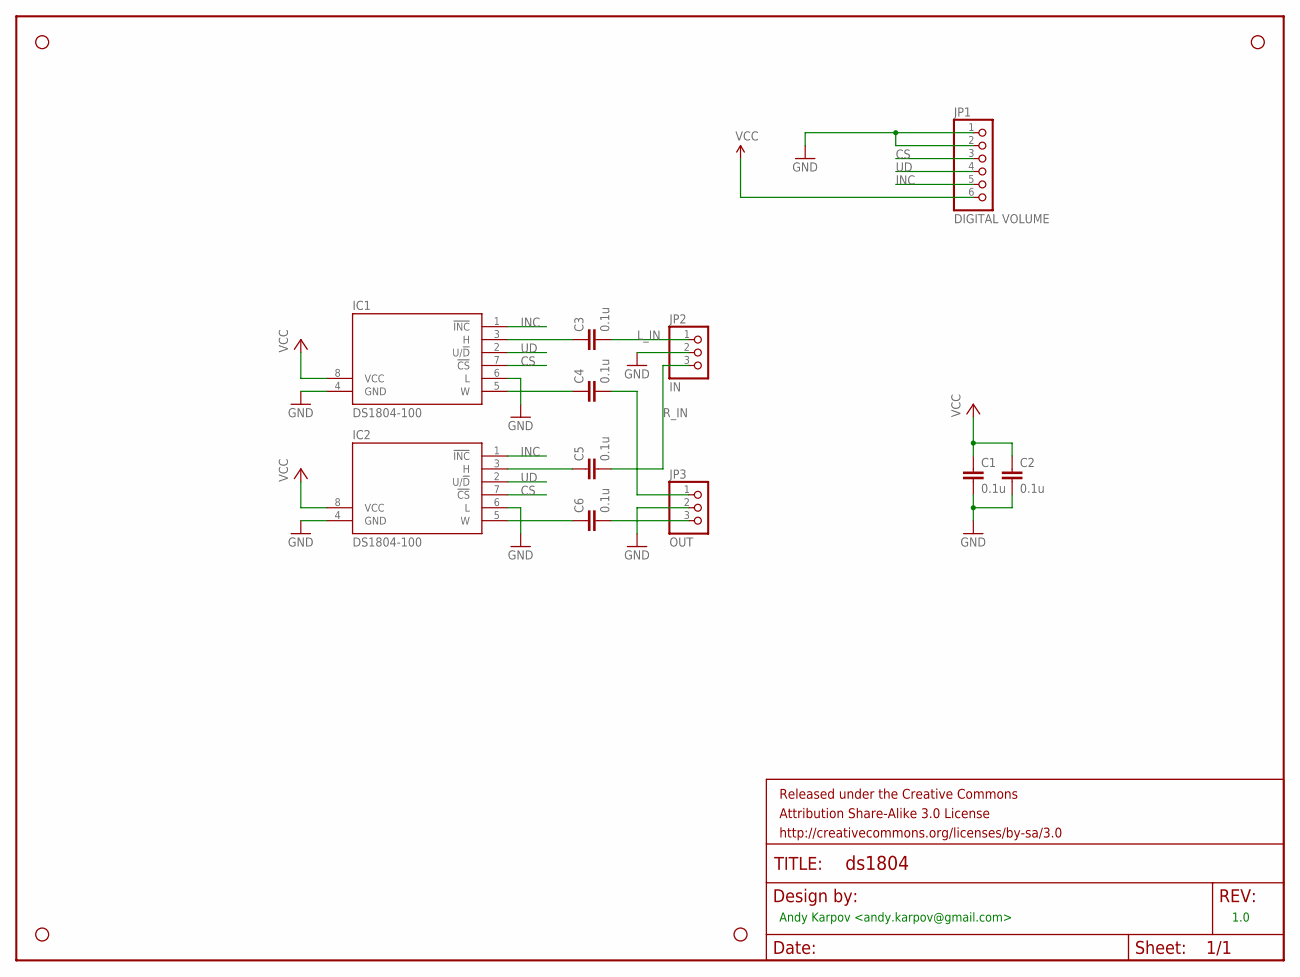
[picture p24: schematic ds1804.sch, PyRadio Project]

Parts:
C1, C2, C3, C4, C5, C6: 0.1u; C025-025X050
FRAME1: FRAME-LETTER; CREATIVE_COMMONS
IC1, IC2: DS1804-100; DIL08
JP1: DIGITAL VOLUME; 1X06
JP2: IN; 1X03
JP3: OUT; 1X03
STANDOFF1, STANDOFF2, STANDOFF3, STANDOFF4: STAND-OFF

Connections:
CS: IC1.7 (!CS), IC2.7 (!CS), JP1.3
GND: C1.2, C2.2, IC1.4 (GND), IC1.6 (L), IC2.4 (GND), IC2.6 (L), JP1.1, JP1.2, JP2.2, JP3.2
INC: IC1.1 (!INC), IC2.1 (!INC), JP1.5
L_IN: C3.2, JP2.1
L_OUT: C4.2, JP3.1
unnamed: C5.1, IC2.3 (H)
unnamed: C6.1, IC2.5 (W)
unnamed: C3.1, IC1.3 (H)
unnamed: C4.1, IC1.5 (W)
R_IN: C5.2, JP2.3
R_OUT: C6.2, JP3.3
UD: IC1.2 (U/!D), IC2.2 (U/!D), JP1.4
VCC: C1.1, C2.1, IC1.8 (VCC), IC2.8 (VCC), JP1.6

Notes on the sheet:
Andy Karpov <andy.karpov@gmail.com>
1.0

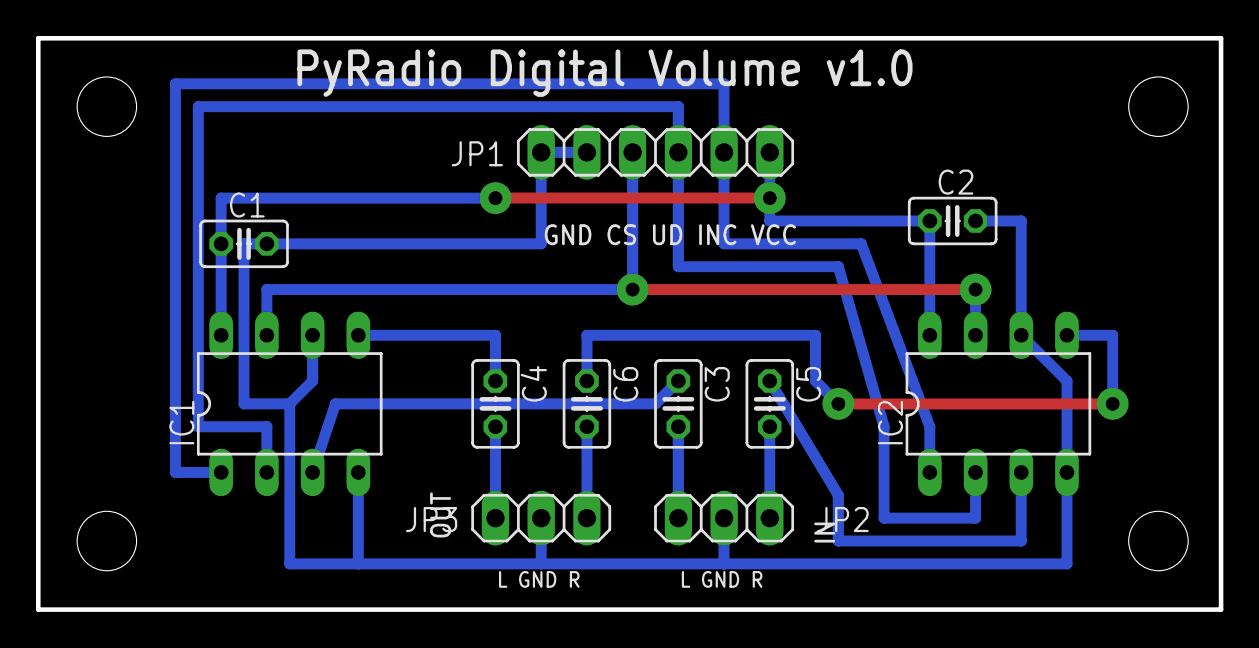
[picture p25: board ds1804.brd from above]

Board: 2 copper layers, 65.7 x 31.7 mm, 16 parts (0 on the bottom side), 13 nets.

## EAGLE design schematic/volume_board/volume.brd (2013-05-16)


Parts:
FRAME1: FRAME-LETTER; CREATIVE_COMMONS
JP1: PINHD-1X3; 1X03
JP2: PINHD-1X2; 1X02
R1: PC16SV - 100k; PC16SV
STANDOFF1, STANDOFF2, STANDOFF3, STANDOFF4: STAND-OFF

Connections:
unnamed: JP1.1, R1.1E
unnamed: JP1.2, R1.1S
unnamed: JP1.3, R1.1A
unnamed: JP2.1, R1.S2
unnamed: JP2.2, R1.S1

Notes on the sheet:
Andy Karpov <andy.karpov@gmail.com>
1.0


Board: 2 copper layers, 25.1 x 34.3 mm, 8 parts (0 on the bottom side), 5 nets.

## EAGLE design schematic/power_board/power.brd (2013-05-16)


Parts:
FRAME1: FRAME-LETTER; CREATIVE_COMMONS
J1: POWER_JACKPTH; POWER_JACK_PTH
JP1: PWR_AMP; 1X02
JP2: PWR_PI; 1X02
JP3: PWR_LCD; 1X02
JP4: USB-B; USB-B-PTH
JP5: AUDIO; 1X05
JP6: USB; 1X04
STANDOFF1, STANDOFF2, STANDOFF3, STANDOFF4: STAND-OFF
U$1: AUDIO-JACK2PTH; AUDIO-JACK

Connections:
GND: J1.GND, J1.GNDBREAK, JP1.2, JP2.2, JP3.2, JP4.GND, JP5.3, JP6.1, U$1.SLEEVE
unnamed: JP4.D+, JP6.4
unnamed: JP5.2, U$1.RSH
unnamed: JP5.1, U$1.RING
unnamed: JP4.VBUS, JP6.2
unnamed: JP4.D-, JP6.3
unnamed: JP5.5, U$1.TIP
unnamed: JP5.4, U$1.TSH
VCC: J1.PWR, JP1.1, JP2.1, JP3.1

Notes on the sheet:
Andy Karpov <andy.karpov@gmail.com>
1.0


Board: 2 copper layers, 68.6 x 26.7 mm, 13 parts (0 on the bottom side), 9 nets.

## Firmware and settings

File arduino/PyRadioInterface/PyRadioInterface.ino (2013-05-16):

/*
 * Raspberry Pi internet radio project
 * Arduino based front-end using serial communication, 20x4LCD, potentiometer, encoder, 2x MSGEQ7, PT2322 board
 *
 * @author Andrey Karpov <andy.karpov@gmail.com>
 * @copyright 2013 Andrey Karpov
 */

#include <LiquidCrystal.h>
#include <Encoder.h>
#include <Button.h>
#include <Led.h>
#include <Wire.h>
#include <PT2322.h>
#include <EEPROM.h>

#define ROWS 4 // number of display rows
#define COLS 20 // number of display columns
#define NUM_READINGS 1 // number of analog reading to average it's value
#define SERIAL_SPEED 115200 // serial port speed
#define SERIAL_BUF_LEN 64 // serial reading buffer

#define MSGEQ_STROBE 6 // В6
#define MSGEQ_RESET 5 // D5
#define MSGEQ_OUT_L 2 // A2
#define MSGEQ_OUT_R 3 // A3

#define PT2322_MIN_VOLUME -79 // dB
#define PT2322_MAX_VOLUME 0 // dB
#define PT2322_MIN_TONE -14 // db
#define PT2322_MAX_TONE 14 // db

#define NUM_MODES 5 // number of app modes

#define EEPROM_ADDRESS_OFFSET 400 // address offset to start reading/wring to the EEPROM 

#define DELAY_VOLUME 3000 // volume bar show decay  
#define DELAY_ENCODER 100 // delay between sending encoder changes back to Pi 
#define DELAY_MODE 400 // mode switch debounce delay
#define DELAY_EEPROM 10000 // delay to store to the EEPROM

PT2322 audio; // PT2322 board connected to i2c bus (GND, A4, A5)
LiquidCrystal lcd(8, 9, 13, 12, 11, 10); // lcd connected to D8, D9, D13, D12, D11, D10 pins
Encoder enc(2, 3); // encoder pins A and B connected to D2 and D3 
Button btn(4, PULLUP); // encoder's button connected to GND and D4
Button btn_mode(15, PULLUP); // mode button connected to GND and A1
Led backlight(7); // LCD backlight connected to GND and D7

char buf[SERIAL_BUF_LEN]; // serial buffer
byte index = 0; // current buffer position
char sep = ':';  // incoming command separator

bool buffering = true; // buffering mode, default to On
bool need_enc = false; // need to send encoder value to the Pi backend, default to false
bool need_vol = false; // need to send volume value to the Pi backend, default to false
bool init_done = false; // boot done (pyradio service has been started and sent initial data), default to false

int station = 0; // current station value
int prev_station = 0; // previous encoder value
int max_stations = 0; // max stations value

int vol = 0; // current volume value
int prev_vol = 0; // previous volume value
int max_vol = 100; // max volume value

unsigned long last_vol = 0; // timestamp of last volume changed
unsigned long last_enc = 0; // timestamp of last encoder changed

String t[ROWS]; // LCD buffer
String prev_t[ROWS]; // LCD previous buffer

int eq_L[7] = {0,0,0,0,0,0,0}; // 7-band equalizer values for left channel
int eq_R[7] = {0,0,0,0,0,0,0}; // 7-band equalizer values for right channel

// enum with application states
enum app_mode_e {
  app_mode_station = 0,
  app_mode_eq,
  app_mode_tone_bass,
  app_mode_tone_mid,
  app_mode_tone_treble
};

int mode = app_mode_station; // mode set to default (station display)
bool mode_changed = true; // mode button has been pressed
unsigned long last_mode = 0; // timestamp of last mode changed

int tones[3]; // bass, mid, treble
int prev_tones[3]; // bass, mid, treble
bool need_store = false; // flag if we need to store something to the EEPROM
unsigned long last_tone = 0; // timestamp of last tone change

// custom LCD characters (volume bars)
byte p1[8] = { 0b10000, 0b10000, 0b10000, 0b10100, 0b10100, 0b10000, 0b10000, 0b10000 };
byte p2[8] = { 0b10100, 0b10100, 0b10100, 0b10100, 0b10100, 0b10100, 0b10100, 0b10100 };  
byte p3[8] = { 0b10101, 0b10101, 0b10101, 0b10101, 0b10101, 0b10101, 0b10101, 0b10101 };
byte p4[8] = { 0b00101, 0b00101, 0b00101, 0b00101, 0b00101, 0b00101, 0b00101, 0b00101 };
byte p5[8] = { 0b00001, 0b00001, 0b00001, 0b00101, 0b00101, 0b00001, 0b00001, 0b00001 };
byte p6[8] = { 0b00000, 0b00000, 0b00000, 0b00100, 0b00100, 0b00000, 0b00000, 0b00000 };
byte p7[8] = { 0b00000, 0b00001, 0b00011, 0b00111, 0b00111, 0b00011, 0b00001, 0b00000 };
byte p8[8] = { 0b00000, 0b10000, 0b11000, 0b11100, 0b11100, 0b11000, 0b10000, 0b00000 };

// custom LCD characters (eq bars)
byte e1[8] = { 0b00000, 0b00000, 0b00000, 0b00000, 0b00000, 0b00000, 0b11111, 0b11111 };
byte e2[8] = { 0b00000, 0b00000, 0b00000, 0b11111, 0b11111, 0b00000, 0b11111, 0b11111 };  
byte e3[8] = { 0b11111, 0b11111, 0b00000, 0b11111, 0b11111, 0b00000, 0b11111, 0b11111 };
byte e4[8] = { 0b00000, 0b00000, 0b00000, 0b00000, 0b00000, 0b00000, 0b00000, 0b00000 };

/**
 * Load custom LCD characters for volume control
 */ 
void loadVolumeCharacters() {
  lcd.createChar(1, p1);
  lcd.createChar(2, p2);
  lcd.createChar(3, p3);
  lcd.createChar(4, p4);
  lcd.createChar(5, p5);
  lcd.createChar(6, p6);
  lcd.createChar(7, p7);
  lcd.createChar(8, p8);
}

/**
 * Load custom LCD characters for graphical equalizer bars
 */
void loadEqualizerCharacters() {
  lcd.createChar(1, e1);
  lcd.createChar(2, e2);
  lcd.createChar(3, e3);
  lcd.createChar(4, e4);
}

/**
 * Arduino setup routine
 */
void setup() {

  // set A0 as input for volume regulator
  pinMode(A0, INPUT);
  
  // set default tones
  for (int i=0; i<3; i++) {
    tones[i] = 0;
    prev_tones[i] = 0;
  }
  
  // restore saved tone values from EEPROM
  restoreTones();
  
  // read volume knob position
  vol = readVolume();
  
  // init PT2322 board
  Wire.begin();
  audio.init();
  delay(100);
  
  // send volume and tones to the PT2322 board
  sendPT2322();
  
  // setup MSGEQ board
  pinMode(MSGEQ_STROBE, OUTPUT);
  pinMode(MSGEQ_RESET, OUTPUT);
  analogReference(DEFAULT);
  pinMode(A2, INPUT);
  pinMode(A3, INPUT);
  
  // setup lcd
  lcd.begin(COLS, ROWS);
  lcd.clear();
  loadVolumeCharacters();  
  
  // setup serial
  Serial.begin(SERIAL_SPEED);
  Serial.flush();
  
  // on backlight    
  backlight.on();
  
  // set default values to display buffers
  t[0] = "";
  t[1] = "";
  t[2] = "";
  t[3] = "";  
  
  // send "init" command to the Raspberry Pi backend
  Serial.println("init");  
}

/**
 * Application mode to handle station display
 * @param unsigned long current - current timestamp
 */
void AppStation(unsigned long current) {
  if (mode_changed) {
    lcd.clear();
    loadVolumeCharacters();
    mode_changed = false;
    prev_t[0] = "__";
    prev_t[1] = "__";
    prev_t[2] = "__";
    prev_t[3] = "__";
    setEncoder(station);
  }
  
  if (init_done) {
    
    station = readEncoder(max_stations);
  
    if (station != prev_station) {
      printStation(station);
      prev_station = station;
      last_enc = current;
      need_enc = true;
    }

    for (int i=0; i<2; i++) {
      if (prev_t[i] != t[i]) { 
        int l = t[i].length();
        if (l < COLS) {
          for (int j=l; j<COLS; j++) {
            t[i] += ' ';
          }
        }
        lcd.setCursor(0,i);
        lcd.print(t[i].substring(0, COLS));
        prev_t[i] = t[i];
    }
  }

  if (current - last_vol <= DELAY_VOLUME) {
      lcd.setCursor(0,2);
      lcd.print("VOLUME ");
      lcd.print(vol);
      lcd.print("  ");
      lcd.setCursor(10,2);
      lcd.print("          ");
      lcd.setCursor(0,3);
      printBar(vol);
      for (int i=0; i<ROWS; i++) {
        prev_t[i] = "___";
      }
    } else {
      for (int i=2; i<ROWS; i++) {
        if (prev_t[i] != t[i]) { 
          int l = t[i].length();
          if (l < COLS) {
            for (int j=l; j<COLS; j++) {
              t[i] += ' ';
            }
          }
          lcd.setCursor(0,i);
          lcd.print(t[i].substring(0, COLS));
          prev_t[i] = t[i];
        }
      }
    }
      
    // send encoder and volume to serial port with a small delay  
    if ((need_enc) && (current - last_enc >= DELAY_ENCODER)) {
      Serial.print(station);
      Serial.print(":");
      Serial.println(100);
      need_enc = false;
    }
  }
}

/**
 * Application mode to display a graphical equalizer (2x 7-band)
 * @param unsigned long current - current timestamp
 */
void AppEq(unsigned long current) {
  if (mode_changed) {
    lcd.clear();
    loadEqualizerCharacters();
    mode_changed = false;
  }
  
  readMsgeq();

  lcd.setCursor(0, ROWS-1);
  lcd.print("L");
  lcd.setCursor(COLS-1, ROWS-1);
  lcd.print("R");
  
  for (int i=0; i<7; i++) {
    int val_L = map(eq_L[i], 0, 1023, 0, 8 * ROWS);
    int val_R = map(eq_R[i], 0, 1023, 0, 8 * ROWS);
    for (int j=0; j<ROWS; j++) {
      int mx = 8*(j+1);
      int v_l = (val_L >= mx) ? 8 : val_L - mx + 8;
      if (v_l < 0) v_l = 0;
      int v_r = (val_R >= mx) ? 8 : val_R - mx + 8;
      if (v_r < 0) v_r = 0;
      
      lcd.setCursor(i + ((COLS == 20) ? 2 : 1), ROWS-j-1);
      if (v_l == 1 || v_l == 2 || v_l == 3) lcd.write(1);
      if (v_l == 4 || v_l == 5 || v_l == 6) lcd.write(2);
      if (v_l == 7 || v_l >= 8) lcd.write(3);
      if (v_l == 0) lcd.write(4);

      lcd.setCursor(i + ((COLS == 20) ? 11 : 8), ROWS-j-1);
      if (v_r == 1 || v_r == 2 || v_r == 3) lcd.write(1);
      if (v_r == 4 || v_r == 5 || v_r == 6) lcd.write(2);
      if (v_r == 7 || v_r >= 8) lcd.write(3);
      if (v_r == 0) lcd.write(4);
    }
    //delay(2);
  }  
}

/**
 * Application mode to control Bass tone
 * @param unsigned long current - current timestamp
 */
void AppToneBass(unsigned long current) {
  if (mode_changed) {
    lcd.clear();
    loadVolumeCharacters();
    mode_changed = false;
    setEncoder(tones[0]);
  }
  tones[0] = readEncoder(100);
  lcd.setCursor(0,2);
  lcd.print("BASS ");
  lcd.print(tones[0]);
  lcd.print("  ");
  lcd.setCursor(0,3);
  printBar(tones[0]);
}

/**
 * Application mode to control Mid tone
 * @param unsigned long current - current timestamp
 */
void AppToneMid(unsigned long current) {
 if (mode_changed) {
    lcd.clear();
    loadVolumeCharacters();
    mode_changed = false;
    setEncoder(tones[1]);
  }
  tones[1] = readEncoder(100);
  lcd.setCursor(0,2);
  lcd.print("MIDDLE ");
  lcd.print(tones[1]);
  lcd.print("  ");
  lcd.setCursor(0,3);
  printBar(tones[1]);
}

/**
 * Application mode to control Treble tone
 * @param unsigned long current - current timestamp
 */
void AppToneTreble(unsigned long current) {
 if (mode_changed) {
    lcd.clear();
    loadVolumeCharacters();
    mode_changed = false;
    setEncoder(tones[2]);
  }
  tones[2] = readEncoder(100);
  lcd.setCursor(0,2);
  lcd.print("TREBLE ");
  lcd.print(tones[2]);
  lcd.print("  ");
  lcd.setCursor(0,3);
  printBar(tones[2]);
}

/**
 * Main application loop
 */ 
void loop() {

  unsigned long current = millis();
    
  vol = readVolume();

  if (btn.isPressed() && current - last_mode >= DELAY_MODE) {
    last_mode = current;
    if (mode == NUM_MODES-1) {
      mode = 0;
    } else {
      mode = mode++;
    }
    mode_changed = true;
  }

  if (abs(vol-prev_vol) > 2) {
    prev_vol = vol;
    last_vol = current;
    need_vol = true;
    sendPT2322();
  }
  
  if (tones[0] != prev_tones[0] || tones[1] != prev_tones[1] || tones[2] != prev_tones[2]) {
    last_tone = current;
    prev_tones[0] = tones[0];
    prev_tones[1] = tones[1];
    prev_tones[2] = tones[2];
    need_store = true;
    sendPT2322();
  }
  
  // store settings in EEPROM with delay to reduce number of EEPROM write cycles
  if (need_store && current - last_tone >= DELAY_EEPROM) {
      storeTones();
      need_store = false;
  }
  
  switch (mode) {
    case app_mode_station:
      AppStation(current);
    break;
    case app_mode_eq:
      AppEq(current);
    break;
    case app_mode_tone_bass:
      AppToneBass(current);
    break;
    case app_mode_tone_mid:
      AppToneMid(current);
    break;
    case app_mode_tone_treble:
      AppToneTreble(current);
    break;

  }
  
   readLine();
   if (!buffering) {
     processInput();
     index = 0;
     buf[index] = '\0';
     buffering = true;
   } 
 
   //delay(20);  
}

/** 
 * Load stored tone control values from the EEPROM (into the tones and prev_tones)
 */
void restoreTones() {
  
  byte value;
  int addr;
  
  // bass / mid / treble
  for (int i=0; i<3; i++) {
    addr = i + EEPROM_ADDRESS_OFFSET;
    value = EEPROM.read(addr);
    // defaults
    if (value < 0 || value > 100) {
      value = 0;
    }
    tones[i] = value;
    prev_tones[i] = value;
  }  
}

/**
 * Store tone value in the EEPROM
 * @param int mode
 */
void storeTone(int mode) {
  int addr = mode + EEPROM_ADDRESS_OFFSET;
  EEPROM.write(addr, tones[mode]);  
}

/**
 * Store tone values in the EEPROM
 */
void storeTones() {
  // bass / treble / balance
  for (int i=0; i<3; i++) {
    storeTone(i);
  }
  int addr;
}

/**
 * Send tone control values to the PT2322
 */
void sendPT2322() {
  audio.masterVolume(map(vol, 0, 100, PT2322_MIN_VOLUME, PT2322_MAX_VOLUME));
  audio.leftVolume(0);
  audio.rightVolume(0);
  audio.centerVolume(-15); // off
  audio.rearLeftVolume(-15); // off
  audio.rearRightVolume(-15); // off
  audio.subwooferVolume(-15); // off
  audio.bass(map(tones[0], 0, 100, PT2322_MIN_TONE, PT2322_MAX_TONE));
  audio.middle(map(tones[1], 0, 100, PT2322_MIN_TONE, PT2322_MAX_TONE));
  audio.treble(map(tones[2], 0, 100, PT2322_MIN_TONE, PT2322_MAX_TONE));
  audio._3DOff(); // 3d
  audio.toneOn(); // tone Defeat
  audio.muteOff(); // mute off
}

/**
 * Read equalizer data from the 2xMSGEQ7 chips into the eq_L and eq_R arrays
 */
void readMsgeq() {
  digitalWrite(MSGEQ_RESET, HIGH);
  digitalWrite(MSGEQ_RESET, LOW);
  for (int i = 0; i < 7; i++) {
    digitalWrite(MSGEQ_STROBE, LOW);
    delayMicroseconds(30);
    eq_L[i] = analogRead(MSGEQ_OUT_L);
    eq_R[i] = analogRead(MSGEQ_OUT_R);
    digitalWrite(MSGEQ_STROBE,HIGH);
  }
  digitalWrite(MSGEQ_RESET, LOW);
  digitalWrite(MSGEQ_STROBE, HIGH);
}

/**
 * Read volume from the potentiometer
 * @return int
 */
int readVolume() {

  int values[NUM_READINGS];
  
  for (int i=0; i<NUM_READINGS; i++) {
    values[i] = map(analogRead(A0), 0, 1023, 0, max_vol);
  }

  int total = 0;
  
  for (int i=0; i<NUM_READINGS; i++) {
    total = total + values[i];
  }
  
  int value = total / NUM_READINGS;
  
  if (value >= max_vol) {
    value = max_vol;
  }
  
  if (value <= 0) {
    value = 0;
  }

  return value;
}

/**
 * Read encoder value with bounds from 0 to max_encoder_value
 * @param int max_encoder_value
 */
int readEncoder(int max_encoder_value) {
  int value = enc.read() / 4;
  if (value > max_encoder_value) {
    value = max_encoder_value;
    setEncoder(max_encoder_value);
  }
  if (value < 0) {
    value = 0;
    setEncoder(0);
  }
  return value;
}

/**
 * Save encoder value
 * @param int value
 */
void setEncoder(int value) {
  enc.write(value * 4);
}

 /**
  * Fill internal buffer with a single line from the serial port 
  *
  * @return void
  */
 void readLine() {
   if (Serial.available())  {
     while (Serial.available()) {
         char c = Serial.read();
         if (c == '\n' || c == '\r' || index >= SERIAL_BUF_LEN) {
           buffering = false;
         } else {
           buffering = true;
           buf[index] = c;
           index++;
           buf[index] = '\0';
         }
     }
   }
 }
 
 /**
  * Routine to compare input line from the serial port and perform a response, if required
  *
  * @return void
  */
 void processInput() {
     String content = String(buf);
  
     int pos = content.indexOf(sep);
     if (content.length() == 0 || pos < 0) return;
  
     String cmd = content.substring(0, pos);
     String arg = content.substring(pos+1);
     int arg_pos = arg.indexOf(sep);
     String arg1 = arg.substring(0, arg_pos);
     String arg2 = arg.substring(arg_pos+1);

     // command T1:<some text> will print text on the first line of the lcd
     if (cmd.compareTo("T1") == 0) {
         t[0] = arg;
     } 

     // command T2:<some text> will print text on the second line of the lcd, if allowed    
     if (cmd.compareTo("T2") == 0) {
         t[1] = arg;
     }

     // command T3:<some text> will print text on the third line of the lcd, if allowed
     if (cmd.compareTo("T3") == 0) {
         t[2] = arg;
     }

     // command T4:<some text> will print text on the fourth line of the lcd, if allowed
     if (cmd.compareTo("T4") == 0) {
         t[3] = arg;
     }
          
     // done init
     if (cmd.compareTo("D") == 0) {
       station = stringToInt(arg1);
       max_stations = stringToInt(arg2);
       printStation(station);
       t[2] = arg1;
       t[3] = arg2;
       init_done = true;
       mode_changed = true;
       need_vol = true;
       prev_vol = -1; // force show volume
     }
 }
 
 /**
  * Conver string object into signed integer value
  *
  * @param String s
  * @return int
  */
 int stringToInt(String s) {
     char this_char[s.length() + 1];
     s.toCharArray(this_char, sizeof(this_char));
     int result = atoi(this_char);     
     return result;
 }

/**
 * Print station name and index into the LCD buffer
 */
void printStation(int s) {
    String station_id = String(s+1);
    String station_count = String(max_stations+1);
    t[1] = station_id + " / " + station_count;
    t[2] = "";
    t[3] = "";
    prev_t[0] = "-";
    prev_t[1] = "-";
    prev_t[2] = "-";
    prev_t[3] = "-";
}

 /** 
  * Pring a progress bar on the current cursor position
  *
  * @param int percent
  */
 void printBar(int percent) {

   double length = COLS + 0.0;
   double value = length/100*percent;
   int num_full = 0;
   double value_half = 0.0;
   int peace = 0;
   
   // fill full parts of progress
   if (value>=1) {
    for (int i=1;i<value;i++) {
      lcd.write(3); 
      num_full=i;
    }
    value_half = value-num_full;
  } else {
    value_half = value;
  }
  
  // fill partial part of progress
  peace=value_half*5;
  
  if (peace > 0 && peace <=5) {
    if (peace == 1 || peace == 2) lcd.write(1);
    if (peace == 3 || peace == 4) lcd.write(2);
    if (peace == 5) lcd.write(3);
  }
  
  // fill spaces
  int spaces = length - num_full;
  if (peace) {
    spaces = spaces - 1;
  }
  for (int i =0;i<spaces;i++) { 
    lcd.write(6);
  }  
 }

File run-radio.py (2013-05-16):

#!/usr/bin/env python
# -*- coding: utf-8 -*-

import re
import codecs
import time
import serial
import textwrap
from mpd import MPDClient, MPDError, CommandError

try:
    import alsaaudio
    alsa_lib_exists = True
except ImportError:
    alsa_lib_exists = False
    pass

# force to not use alsa volume control yet
alsa_lib_exists = False

def debug(message):
    if Config.debug:
        print message


class Config:

    COLS = 20
    ROWS = 4

    debug = True

    serial_dev = ["/dev/ttyAMA0"]
    serial_speed = 115200

    sound_card = 1
    mixer_channel = 'Speaker'

    playlist = "/home/pi/PiRadio/data/radio.m3u"
    state = "/home/pi/PiRadio/data/state.txt"
    save_timeout = 500

    mpd_host = "localhost"
    mpd_port = 6600
    mpd_password = None

    init_delay = 0.1
    write_delay = 0.35
    read_delay = 0.1


class Interface:

    serial = None
    serial_connected = False

    encoder = 0
    volume = 0

    min_value = 0
    max_value = 0

    min_volume = 0
    max_volume = 100

    stations = []

    def __init__(self, encoder=0, min_value=0, max_value=0, stations=[]):
        self.encoder = encoder
        self.min_value = min_value
        self.max_value = max_value
        self.stations = stations
        self.try_serial()

    def send_init(self):
#        self.serial.write('M:' + str(self.max_value) + "\r\n")
#        debug("write: " + 'M:' + str(self.max_value))
#        time.sleep(Config.write_delay)
#        self.serial.write('E:' + str(self.encoder) + "\r\n")
#        debug("write: " + 'E:' + str(self.encoder))
#        time.sleep(Config.write_delay)
#        i = 0
#        for station in self.stations:
#            i += 1
#            self.serial.write('S' + str(i) + ':' + station.name.upper() + "\r\n")
#            debug("write: " + 'S' + str(i) + ':' + station.name.upper())
#            time.sleep(Config.write_delay)
	self.serial.write("\r\n");
	time.sleep(Config.write_delay);
	self.serial.write("\r\n");
	time.sleep(Config.write_delay);
        self.serial.write('D:' + str(self.encoder) + ':' + str(self.max_value) + "\r\n")
        debug("write: " + 'D:' + str(self.encoder) + ':' + str(self.max_value))
        time.sleep(Config.write_delay)

    def try_serial(self):
        for serial_dev in Config.serial_dev:
            if not self.serial_connected:
                try:
                    # try to reset first
                    # self.serial = serial.Serial(serial_dev, 1200)
                    # time.sleep(Config.init_delay)
                    # self.serial.close();
                    # try to open normally
                    self.serial = serial.Serial(serial_dev, Config.serial_speed)
                    time.sleep(Config.init_delay)
                    self.serial_connected = True
                    self.send_init()
                    debug("serial port: " + serial_dev)
                except Exception as e:
                    debug(e)
                    self.serial_connected = False

    def try_write(self, data):
        try:
            self.serial.write(data + "\r\n")
            debug("write: " + data)
            time.sleep(Config.write_delay)
            return True
        except Exception as e:
            self.serial_connected = False
            self.try_serial()
            return False

    def try_read(self):
        init_request = False
        try:
            if self.serial_connected and self.serial.inWaiting():
                ln = self.serial.readline()
                ln = ln.strip()
                debug("read: " + ln)
                if ln == "init":
                    time.sleep(Config.init_delay)
                    self.send_init()
                    init_request = True
                elif ln != "":
                    parts = ln.split(":", 2)
                    self.encoder = int(parts[0])
                    self.volume = int(parts[1])
                    if self.volume <= 2:
                        self.volume = 0
                    if self.volume >= 98:
                        self.volume = 100
            elif not self.serial_connected:
                self.try_serial()
            return init_request
        except Exception as e:
            return None

    def set_enc(self, value):
        return self.try_write('E:' + str(value))


class PollerError(Exception):
    """Fatal error in poller."""


class MPDWrapper:

    def __init__(self, host="localhost", port="6600", password=None):
        self._host = host
        self._port = port
        self._password = password
        self._client = MPDClient()

    def connect(self):
        try:
            self._client.connect(self._host, self._port)

        except IOError as (errno, strerror):
            raise PollerError("Could not connect to '%s': %s" % (self._host, strerror))

        except MPDError as e:
            raise PollerError("Could not connect to '%s': %s" % (self._host, e))

        if self._password:
            try:
                self._client.password(self._password)

            except CommandError as e:
                raise PollerError("Could not connect to '%s': "
                                  "password command failed: %s" %
                                  (self._host, e))

            except (MPDError, IOError) as e:
                raise PollerError("Could not connect to '%s': "
                                  "error with password command: %s" %
                                  (self._host, e))

    def disconnect(self):
        try:
            self._client.close()

        except (MPDError, IOError):
            pass

        try:
            self._client.disconnect()

        except (MPDError, IOError):
            self._client = MPDClient()

    def currentsong(self):

        try:
            self._client.command_list_ok_begin()
            self._client.currentsong()
            song = self._client.command_list_end()

        except (MPDError, IOError):
            self.disconnect()

            try:
                self.connect()

            except PollerError as e:
                raise PollerError("Reconnecting failed: %s" % e)

            try:
                self._client.command_list_ok_begin()
                self._client.currentsong()
                song = self._client.command_list_end()

            except (MPDError, IOError) as e:
                raise PollerError("Couldn't retrieve current song: %s" % e)

        return song

    def load_playlist(self, list):
        try:
            self._client.command_list_ok_begin()
            self._client.stop()
            self._client.clear()
            for item in list:
                self._client.add(item.url)
            self._client.command_list_end()

        except (MPDError, IOError):
            self.disconnect()

            try:
                self.connect()

            except PollerError as e:
                raise PollerError("Reconnecting failed: %s" % e)
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

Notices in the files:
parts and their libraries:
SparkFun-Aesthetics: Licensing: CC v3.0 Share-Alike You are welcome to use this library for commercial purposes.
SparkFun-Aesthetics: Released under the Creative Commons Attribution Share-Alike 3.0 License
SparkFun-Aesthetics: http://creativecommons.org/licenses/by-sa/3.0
